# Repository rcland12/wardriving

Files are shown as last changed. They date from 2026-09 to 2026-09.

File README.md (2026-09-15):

# rustypi wardriver

A self-contained, touch-driven wardriving rig built on a Raspberry Pi 4B. Power it on and
it boots straight into a full-screen touch UI on a 3.5" LCD. Tap **START** to capture Wi-Fi
and Bluetooth, watch networks scroll by with live GPS and capture stats, and tap **STOP** to
close out the session. Upload finished sessions to WiGLE or your home server from the menu.

<p>
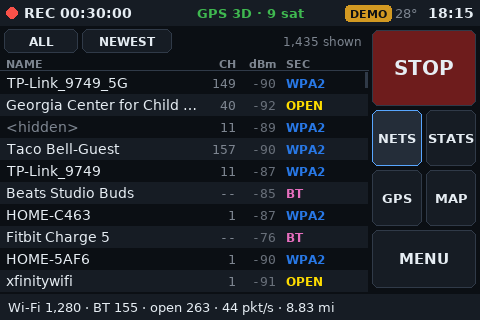
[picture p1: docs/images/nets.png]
Network list

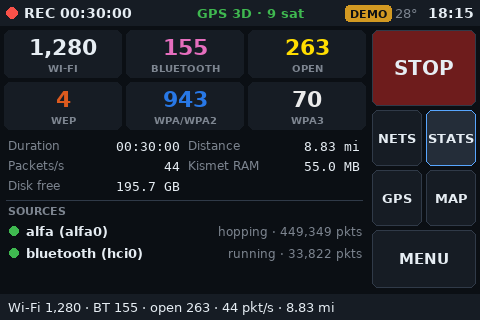
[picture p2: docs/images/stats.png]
Stats view

</p>

> **Status:** alpha. Capture, GPS, Bluetooth, touch calibration and boot-to-UI work on the Pi;
> WiGLE and home-server uploads are implemented. Not yet road-tested.

---

## Hardware

| Part | Model | Role | Linux view |
|---|---|---|---|
| SBC | Raspberry Pi 4 Model B (2 GB) | Host | Raspberry Pi OS Lite 64-bit (Debian 13 "Trixie") |
| Wi-Fi | ALFA AWUS036ACM (MediaTek MT7612U, dual-band) | Capture radio, monitor mode | `alfa0`, pinned by driver match; in-kernel `mt76x2u` |
| Bluetooth | Pi 4 onboard radio | BT classic + BLE capture | `hci0` |
| GPS | GlobalSat BU-353N (USB) | Location + time source | `/dev/serial/by-id/usb-Prolific_…` (NMEA, 4800 baud) |
| Display | OSOYOO 3.5" HDMI LCD, 480x320, resistive touch | UI | HDMI `HDMI-A-1` + ADS7846 touch on SPI0 CE1, IRQ GPIO25 |

The onboard Wi-Fi (`wlan0`) stays in managed mode for SSH and uploads. Only the ALFA captures.

**Display wiring:** video goes over HDMI. Touch uses GPIO header pins 19–26 (SPI MOSI, MISO,
SCLK, CE0, CE1, GPIO25 IRQ, GND). The screen is powered separately, so the 5V pins aren't
needed.

**Orientation:** landscape, rotated 180° so the HDMI adapter points down.

**Case and mount:** a 3D-printable enclosure and dash mount for this exact Pi + screen stack
is in [`case/`](case). See [Case and mount](#case-and-mount).

---

## How it works

```
               ┌──────────────────────────── Raspberry Pi 4B ─────────────────────────────┐
 BU-353N ──USB─┼─► gpsd ──┬──────────────► chrony (sets system clock from GPS; no RTC)    │
               │          ├──────────────► Kismet ◄── alfa0 (monitor mode, 2.4 + 5 GHz)   │
               │          │                  │    ◄── hci0  (Bluetooth / BLE)             │
               │          │                  │  └─► /var/lib/wardrive/logs/*.kismet       │
               │          │                  │                          *.wiglecsv        │
               │          ▼                  ▼ REST API (127.0.0.1:2501)                  │
               │     ┌──────────── wardrive-ui (Python + pygame → /dev/fb0) ─┐            │
               │     │ status bar · nets · stats · gps · map · menu · upload │──► HDMI ───┼─► 3.5" LCD
               │     │ start/stop via systemd · shutdown · WiGLE/home upload │◄── SPI ────┼── touch
               │     └───────────────────────────────────────────────────────┘            │
               └──────────────────────────────────────────────────────────────────────────┘
```

- **Kismet** (from the official Kismet apt repo) does the capture work: monitor mode, channel
  hopping, BLE scanning, GPS tagging, and writing `.kismet` and WiGLE CSV logs. It runs as
  `wardrive-kismet.service`. That service isn't enabled at boot; the START button starts it.
- **gpsd** owns the GPS and polls even with no clients (`-n`), so a fix is ready before you tap
  START. **chrony** takes time from it, so log timestamps are right even with no network.
- **wardrive-ui** draws each frame off-screen with pygame, then copies it into `/dev/fb0`, the
  kernel framebuffer the text console uses. There's no X11, Wayland, or desktop. It renders a
  480x320 canvas, flips it 180°, and scales it to the HDMI mode. It reads the touch panel
  through evdev and maps coordinates with its own 4-point calibration, which covers the axis
  swap and rotation. It controls Kismet through a narrow sudoers rule.
- **systemd** starts the UI on `tty1` in place of the login prompt, about 14 s after power-on,
  and restarts it if it crashes. If the UI restarts mid-capture, it picks the running session
  back up.

### Display notes (OSOYOO 3.5" HDMI)

The OSOYOO panel reached a working setup in three steps:

| Attempt | Result | Why |
|---|---|---|
| Force native `480x320` | "No Signal" | 60 Hz at that size needs an 11.9 MHz pixel clock; HDMI's minimum is 25 MHz |
| Force `640x480` | Signal, but black | The panel lists it in its EDID but doesn't display it |
| **No forced mode** | ✅ Works | The Pi uses the panel's preferred **1280x720**, and the panel's scaler shrinks it to 480x320 |
| SDL straight to DRM/KMS | Black | The UI's buffer reached the display but never showed (likely its alpha channel) |
| **Copy frames into `/dev/fb0`** | ✅ Works | The same opaque buffer the text console uses |

Rotation uses `fbcon=rotate:2`, which flips only the console text. `video=…,rotate=180` would
also rotate everything drawn on the screen, and the app already flips its own frames.
`scripts/display-test.sh` checks each display path one at a time if you change screens.

---

## The UI

| | |
|---|---|
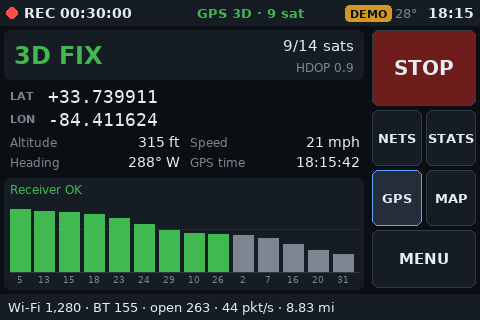
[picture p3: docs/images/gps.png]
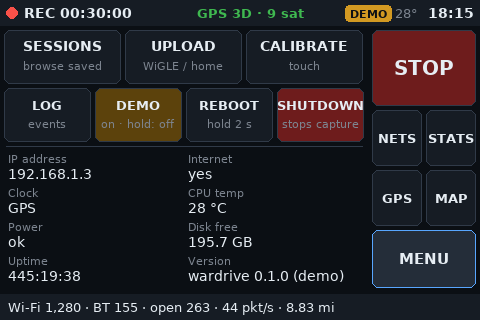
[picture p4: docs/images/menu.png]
|  |  |
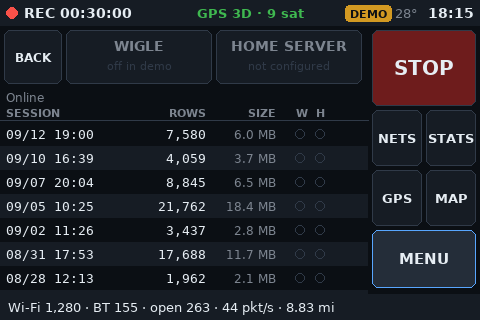
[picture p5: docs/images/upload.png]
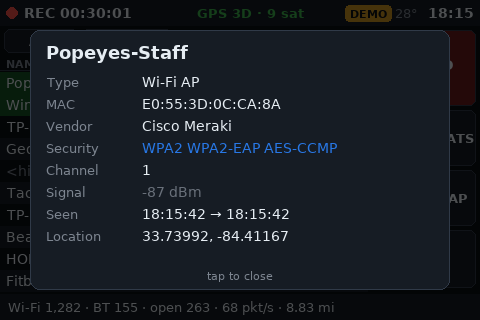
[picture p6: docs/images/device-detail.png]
|  |  |
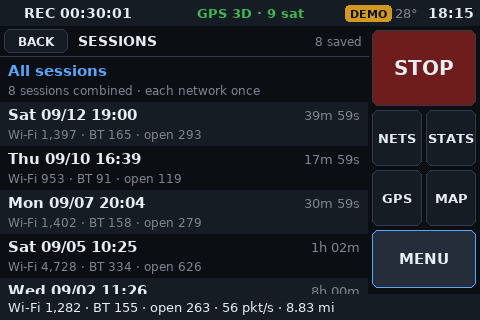
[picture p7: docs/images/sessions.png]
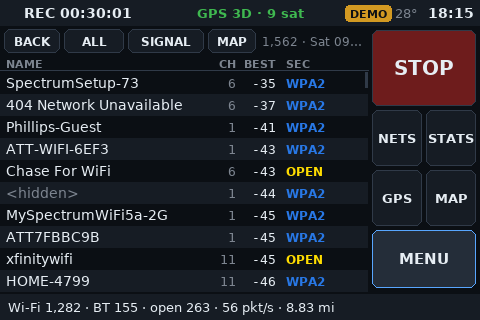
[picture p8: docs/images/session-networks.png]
|  |  |
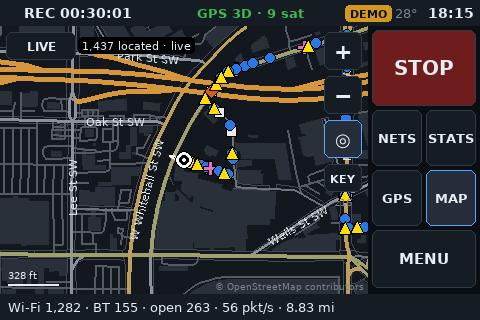
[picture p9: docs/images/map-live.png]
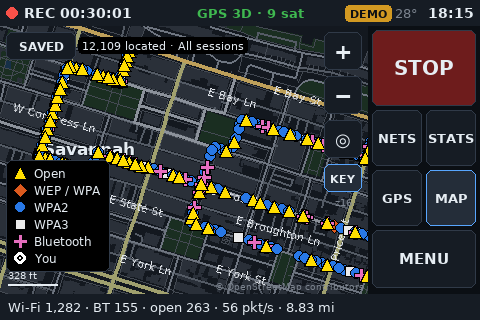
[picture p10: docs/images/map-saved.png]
|  |  |

*(Screenshots use [demo mode](#demo-mode).)*

| View | Shows |
|---|---|
| **NETS** | Live list of Wi-Fi APs and Bluetooth devices. Filter ALL/WIFI/BT; sort newest or strongest. New devices flash green. Tap a row for details. Drag to scroll. |
| **STATS** | Wi-Fi, BT, and per-security counts, duration, distance, packets/s, Kismet RAM, free disk, capture source health. |
| **GPS** | Fix type, satellites, HDOP, lat/lon, altitude, speed, heading, GPS time, clock source. |
| **MAP** | Offline street map (see [Install an offline map](#5-install-an-offline-map-optional)). **LIVE** follows your GPS position and plots networks as they're located; **SAVED** plots a finished session or all of them. Each dot's shape and color show its security: ▲ yellow open, ◆ orange WEP/WPA, ● blue WPA2, ■ white WPA3, ✚ pink Bluetooth; **KEY** shows the legend. The colors are chosen to stay distinct with color blindness, and the shapes work without color at all. Drag to pan, **+**/**−** to zoom, **◎** to re-center and follow. Tap a dot for details. |
| **MENU** | SESSIONS, UPLOAD, CALIBRATE touch, LOG, [DEMO](#demo-mode) (hold 2 s), REBOOT and SHUTDOWN (hold 2 s), IP address, internet, power, temp, disk. |
| **LOG** | App and Kismet events (source errors, GPS fix gained or lost, start/stop). Tap for full text. |
| **SESSIONS** | Finished capture sessions (date, duration, Wi-Fi/BT/open counts, whether archived), plus "All sessions" with each network listed once. Tap one to browse every network it recorded: WIFI/BT filter, sort by strongest signal, name or newest, and tap for details (security and WPS, frequency, strongest signal, packets, sessions seen in, location). **MAP** shows them on the map. |
| **UPLOAD** | Finished sessions with GPS row counts and upload state; one button each for WiGLE and your home server. |

The status bar shows recording time, GPS fix and satellites, CPU temp, a `PWR!` warning for
under-voltage or throttling, and the clock. The footer shows live totals, the last session,
or errors.

---

## Case and mount

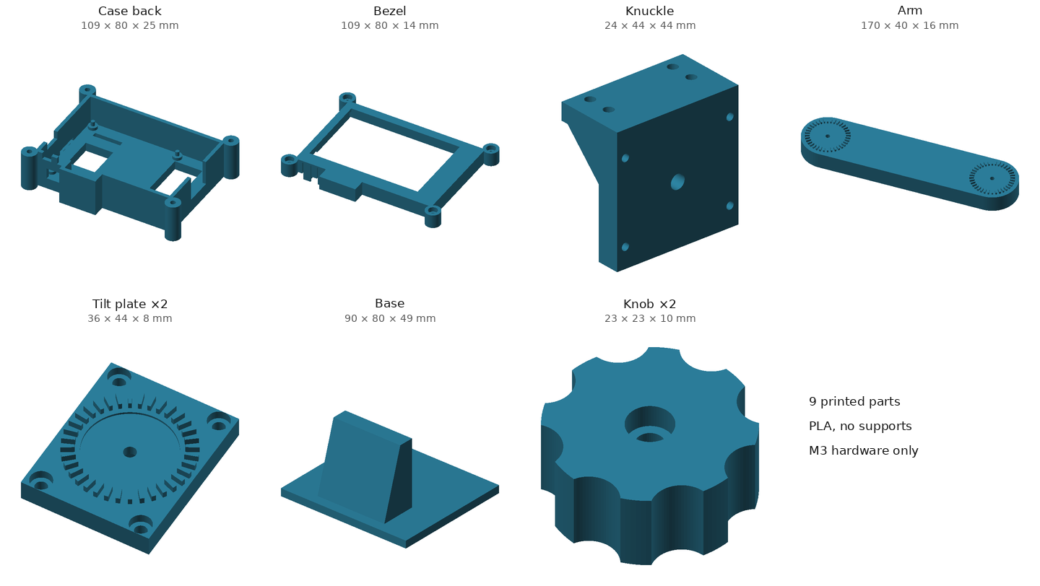
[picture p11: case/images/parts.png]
The nine printed parts of the case and dash mount


A 3D-printable enclosure and car-console mount designed around this exact Pi 4B + OSOYOO
screen stack:
- **Parts:** 9 printed parts, PLA, no supports, M3 hardware only
- **Mount:** an arm with two 10°-step toothed tilt joints, attached to the console with VHB
- **Screen retention:** the bezel clamps the screen by its glass border through foam, so the
  display can't work loose from the GPIO header under vibration
- **Buttons:** flex tabs in the bezel reach the screen's power and backlight buttons

**Full build guide: [`case/README.md`](case/README.md)**, covering parts, hardware, assembly
and design notes. Print settings are in [`case/docs/PRINTING.md`](case/docs/PRINTING.md).

| Files | For |
|---|---|
| [`case/models/stl/`](case/models/stl) | Printing, in any slicer |
| [`case/models/step/`](case/models/step) | Editing in any CAD tool |
| [`case/models/f3d/`](case/models/f3d) | Editing in Fusion 360 |
| [`case/scripts/fusion_build.py`](case/scripts/fusion_build.py) | The parametric source that generates every part |

Print order in brief: both tilt plates first (check that the teeth mesh), then the bezel
(dry-fit it on the screen), then everything else.

---

## Setup

### 1. Flash the Pi
Raspberry Pi OS **Lite** (64-bit). No desktop is needed. In Raspberry Pi Imager, set the
hostname, user, Wi-Fi, SSH key, and Wi-Fi country.

### 2. Deploy from a dev machine
```bash
git clone git@github.com:rcland12/wardriving.git && cd wardriving
./scripts/deploy.sh rustypi7 --boot --reboot
```
Or run it on the Pi from a clone:
```bash
sudo ./scripts/install.sh && sudo ./scripts/boot-config.sh && sudo reboot
```

`install.sh` is idempotent. It does the following:

1. Installs gpsd, chrony, pygame, evdev, `libdrm-tests` (for `display-test.sh`), and Kismet
   (`kismet-core` plus the linux-wifi and linux-bluetooth capture helpers) from Kismet's repo.
2. Pins the ALFA as `alfa0` and tells NetworkManager to leave it alone.
3. Configures gpsd for the GPS and adds it to chrony as a time source.
4. Writes `/etc/kismet/kismet_site.conf`, creates `/var/lib/wardrive/logs`, generates Kismet
   REST credentials in `~/.kismet/kismet_httpd.conf`, and unblocks Bluetooth.
5. Installs `wardrive-kismet.service`, the sudoers rule, `/opt/wardrive`, and
   `/etc/wardrive/wardrive.toml` (created from the example only if it doesn't exist yet).
   Then it enables `wardrive-ui.service`.

`boot-config.sh` edits `/boot/firmware` and keeps timestamped backups. It's idempotent, and
`--remove` undoes it:

- **`config.txt`:** `dtparam=spi=on`, the `ads7846` touch overlay (`cs=1`, `penirq=25`), and
  `disable_splash=1`
- **`cmdline.txt`:** `fbcon=rotate:2` (console upside-down to match the mount), hidden cursor,
  no console blanking, quiet boot. No `video=` mode is forced (see
  [Display notes](#display-notes-osoyoo-35-hdmi)). Options:
  `WARDRIVE_QUIET=0` shows boot messages, and `WARDRIVE_HDMI_MODE` forces a mode.

### 3. First boot: calibrate touch
With no calibration saved, the UI opens the calibration screen. Tap the four corner
crosshairs, then the center one to verify. Use the stylus. Then tap around the test pad and
hit DONE. The calibration is saved to `~/.config/wardrive/touch.json`. To redo it later, go
to **MENU → CALIBRATE**.

### 4. Configure uploads (optional)
Edit `/etc/wardrive/wardrive.toml` on the Pi. It's readable only by root and your user, and
is never committed. See [`config/wardrive.toml.example`](config/wardrive.toml.example).
```toml
[upload.wigle]
enabled = true
api_name = "AID..."        # from https://wigle.net/account
api_token = "..."

[upload.home]
enabled = true
url = "https://api.example.com/wardrive/upload"

[upload.home.headers]      # Cloudflare Access service token for this Pi only
CF-Access-Client-Id = "<id>.access"
CF-Access-Client-Secret = "<secret>"
```
Then check the credentials without uploading anything, and restart the UI:
```bash
cd /opt/wardrive && python3 -m wardrive --test-upload
sudo systemctl restart wardrive-ui
```

The home upload gzips each `.kismet` and `.wiglecsv` file and POSTs it to the
`/wardrive/upload` endpoint of your home API, which stores it under
`api/data/wardrive/<session>/`. Files must be under 95 MB after compression, because of
Cloudflare's body limit. Re-sending an identical file is harmless.

### 5. Install an offline map (optional)
The MAP screen works without internet. It reads a prebuilt map file from
`/var/lib/wardrive/maps/`, which you build on a dev machine from an
[OpenStreetMap](https://www.openstreetmap.org) extract. One US state is a few hundred MB.

```bash
source ~/.global_venv/bin/activate && pip install osmium shapely numpy
curl -fLO https://download.geofabrik.de/north-america/us/georgia-latest.osm.pbf
tools/build_map.py georgia-latest.osm.pbf -o georgia.map --name Georgia   # ~25 min, ~1.2 GB RAM
./scripts/push-map.sh georgia.map rustypi7                                # copy to the Pi, restart the UI
```

What's in the map, and the zoom level where it appears:

| Zoom | Features |
|---|---|
| 6+ | Interstates, city names |
| 9–13 | Highways and main roads, towns, large lakes and parks, rivers |
| 14–15 | All streets, villages and neighborhoods, small parks and ponds, streams |
| 16+ | Buildings, street names, service roads and driveways |
| 17–18+ | Shops and amenities, then house numbers |

The file is SQLite with compressed vector tiles at four levels of detail, drawn directly with
pygame. There's no tile server and no network access. On a Pi 4, street-level views render in
about 5–40 ms, and the whole-state view in about a quarter second (a second the first time).
Panning moves the already-drawn image, so it stays smooth. Only one map is used at a time: the
first `*.map` in the directory, alphabetically. Georgia comes to about 250 MB.

Buildings, businesses and house numbers appear only where someone has mapped them in
OpenStreetMap. Downtowns are usually complete; some suburbs have roads only. Rebuild from a
fresh extract to pick up new edits.

Map data © OpenStreetMap contributors, available under the
[Open Database License](https://www.openstreetmap.org/copyright). The attribution shows on the
map screen.

---

## Demo mode

Try everything indoors, with no GPS signal and no real networks: **MENU → hold DEMO**.
The UI restarts with a **DEMO** badge in the status bar, and:

- **GPS** gets a simulated fix at your demo start point.
- **START** drives a simulated car along the offline map's real roads. The network list,
  stats and live map fill up as it hears the routers in nearby houses and businesses. With
  no map installed, it drives a plain street grid instead.
- **STOP** saves the drive as `.kismet` and `.wiglecsv` files, so SESSIONS, MAP and UPLOAD
  all work on it.
- **SESSIONS** starts with 8 simulated past drives from the last three weeks: short errands,
  longer loops around town, and one trip to another city. The same streets have the same
  routers on every drive, so "All sessions" shows networks seen more than once. One drive
  starts with the clock wrong, like a real boot away from Wi-Fi.
- **UPLOAD → HOME SERVER** sends demo sessions to a separate `_demo` folder on the server.
  If the server doesn't support that yet, the Pi refuses and sends nothing.
- **WiGLE uploads are off** in demo mode. Every demo file is marked as simulated, and
  `tools/wardrive_review.py` won't send marked files to WiGLE.

**MENU → hold DEMO** again deletes the demo data and switches back. Your real logs, upload
records and settings aren't touched in either direction. Everything demo mode writes is
under `/var/lib/wardrive/demo/`.

Set the start point to a public spot in your town in `/etc/wardrive/wardrive.toml`:
```toml
[demo]
lat = 33.7490
lon = -84.3880
```

The same controls work from SSH:
```bash
./scripts/demo.sh on           # create demo data (about 20 s on a Pi 4), restart the UI
./scripts/demo.sh status
./scripts/demo.sh regenerate   # new simulated drives
./scripts/demo.sh off          # delete demo data, back to real capture
```

On a desktop, `python -m wardrive --mock --window` runs demo mode with its own data in
`~/.local/state/wardrive/mock-demo`.

On the server, review demo uploads with `tools/wardrive_review.py --demo list` (and `check`
or `fix`). They make good practice for the clock-step and security repairs.

---

## Using it

1. Power on the screen and the Pi together. Put the GPS where it can see the sky.
2. Tap **START**. Until the clock is set from GPS, the button shows **CANCEL / for GPS time**
   and the status bar shows **GPS TIME…**. Capture starts as soon as the time is set, so every
   record has a correct timestamp. At home on Wi-Fi, it starts immediately.
3. Drive, then tap **STOP**. Kismet closes its logs, and a session summary pops up.
4. **MENU → hold SHUTDOWN** before cutting power. If a capture is still running, it's stopped
   cleanly first.
5. **MAP** shows where you've been. Switch it to **SAVED**, or open a session from
   **MENU → SESSIONS** and tap **MAP**.
6. At home on Wi-Fi, go to **MENU → UPLOAD → HOME SERVER** to archive the session, then review
   and publish it from the server (below).

Get logs directly (never deletes anything):
```bash
./scripts/pull-logs.sh rustypi7      # -> ./logs/ (gitignored)
```

### Review, repair, then publish to WiGLE

Sessions go to your own server first, and nothing reaches WiGLE until you've reviewed it.
`tools/wardrive_review.py` (standard library only) works on the server's session directory:

```bash
tools/wardrive_review.py list                 # sessions and status
tools/wardrive_review.py check latest         # validate; exit code 1 on problems
tools/wardrive_review.py fix latest           # write review/<session>.wiglecsv (originals untouched)
tools/wardrive_review.py wigle latest --dry-run
tools/wardrive_review.py wigle latest         # upload the reviewed file; refuses on FAIL or re-upload
tools/wardrive_review.py wigle-status         # WiGLE processing status
```

`check` looks for:
- **Clock changes mid-capture.** Stale and correct FirstSeen times get grouped into clusters,
  and the offset is measured to ±1 s from the Kismet database's packet order.
- **Wrong security type.** Each row is compared with what Kismet recorded for that BSSID.
- Rows without coordinates, implausible times, GPS jumps, and duplicates.

`fix` shifts (or, with `--drop-stale`, removes) rows with the wrong time, rebuilds AuthMode
from the database, and removes duplicates.

> **Kismet 2025.09 bug:** its live WiGLE CSV writer leaves out WPA/RSN details (every network
> looks open) and marks every encrypted network as WPS. The Kismet database has the correct
> values, and `fix` rebuilds them from it. Always run `fix` before uploading.

Settings are in `~/.config/wardrive/review.env` (`chmod 600`):
```
WARDRIVE_DATA=/path/to/api/data/wardrive
WIGLE_API_NAME=AID...        # wigle.net → Account → API Name
WIGLE_API_TOKEN=...          # API Token (not "Encoded for use")
WIGLE_DONATE=on              # allow WiGLE commercial use of your uploads
```
With this setup, leave `[upload.wigle]` on the Pi unconfigured.

### Analyzer web app

`analyzer/` is the web app for every uploaded session, deployed from the rustyserver stack at
https://wardrive.russellland.dev behind Keycloak: a map of every network and Bluetooth device
(street, dark and satellite basemaps, routes, clustering, heatmap), filters that stay in the URL,
a details panel with signal over time and where each device was heard, stats, and a Sessions
page that runs the same check / fix / WiGLE upload as the tool above.

When the Pi uploads, the home API stores the files and tells the analyzer, which loads the
session into Postgres. Reviews and WiGLE upload records live there too; the uploaded files are
never modified. Details in [analyzer/README.md](analyzer/README.md).

---

## Development

The UI runs anywhere pygame does, using a simulated backend:

```bash
source ~/.global_venv/bin/activate
pip install pygame requests pytest
python -m wardrive --mock --window                # demo mode in a desktop window, mouse = touch
python -m wardrive --screenshot docs/images       # render every screen to PNG (headless, demo data)
python -m pytest -q tests                         # calibration, parsing, uploads, UI dispatch
./scripts/deploy.sh --ui-only                     # sync UI code to the Pi and restart it
```

On the Pi:
```bash
journalctl -u wardrive-ui -f                      # UI log
journalctl -u wardrive-kismet -f                  # capture log
sudo systemctl kill -s USR1 wardrive-ui           # save the live screen to /tmp/wardrive-screen-<view>.png
cgps                                              # GPS sanity check
sudo evtest /dev/input/by-path/*spi*              # raw touch events
chronyc sources                                   # is GPS feeding the clock?
```

### Repository layout
```
wardrive/            touch UI package (python3 -m wardrive)
  app.py             main loop, frame (status bar / nav / footer), modals
  backend.py         Kismet service control + REST polling -> State
  kismet.py gps.py sysinfo.py uploads.py
  touch.py           evdev reader + affine calibration
  display.py theme.py widgets.py fmt.py state.py config.py
  sessions.py        finished-session browser: reads .kismet databases, cached
  mapdata.py         offline map file format and reader
  maprender.py       map renderer (pygame + numpy) and network dots
  demo/              demo mode: simulated drives (world.py), Kismet-format files (files.py), backend
  mock.py            minimal in-memory backend for fast UI tests
  views/             nets, stats, gps, map, log, menu, sessions, upload, calibrate
config/              kismet_site.conf, wardrive.toml.example
system/              systemd units, sudoers, NetworkManager/chrony/link files
scripts/             install.sh, boot-config.sh, deploy.sh, pull-logs.sh, push-map.sh, demo.sh, display-test.sh
tools/               wardrive_review.py (server-side review, repair and WiGLE upload)
                     build_map.py (OpenStreetMap extract -> offline .map file)
analyzer/            web app (SvelteKit + Postgres): map, filters, stats, review and WiGLE upload
case/                3D-printable case and dash mount: models, build script, print guide
tests/               hardware-free tests
docs/images/         screenshots (simulated data)
```

---

## Troubleshooting

| Symptom | Check |
|---|---|
| Screen upside down | Set `display.rotate` in `wardrive.toml` (0 or 180) and `WARDRIVE_ROTATE` for `boot-config.sh`, then recalibrate |
| Touch lands in the wrong place | MENU → CALIBRATE. If you can't reach the menu: `rm ~/.config/wardrive/touch.json && sudo systemctl restart wardrive-ui` |
| No touch device | `grep -A4 ADS7846 /proc/bus/input/devices`. Try `WARDRIVE_TOUCH_CS=0 sudo ./scripts/boot-config.sh` |
| "No Signal" | Remove any forced mode: `sudo ./scripts/boot-config.sh` (don't set `WARDRIVE_HDMI_MODE`). Check the pixel clock: `sudo grep 'mode: "[0-9]' /sys/kernel/debug/dri/*/state` (second number, kHz, must be ≥ 25000) |
| Signal but black UI | Console visible when the UI is stopped? Run `sudo PHASES="C D E" ./scripts/display-test.sh` and watch which phases appear. Keep `display.backend = "fbdev"` |
| Screen dead after boot changes | `sudo ./scripts/boot-config.sh --remove && sudo reboot` restores the original boot files |
| GPS NO FIX forever | Get a sky view (it won't lock indoors). Check `cgps` |
| Bluetooth source error | `sudo rfkill unblock bluetooth` |
| START → ERROR | MENU → LOG, then `journalctl -u wardrive-kismet -b` |
| DEMO badge, networks look made up | Demo mode is on: MENU → hold DEMO (or `./scripts/demo.sh off`) |
| MAP says "No map installed" | `ls /var/lib/wardrive/maps/` should list a `.map` file; see [Install an offline map](#5-install-an-offline-map-optional). `journalctl -u wardrive-ui` shows why a file was skipped |

---

## Legal and privacy

- Passive collection of broadcast beacons is generally legal in the US. Don't connect to,
  deauth, or attack networks you don't own. Check your local laws.
- Capture logs contain precise location history and nearby device identifiers. `logs/` and
  capture file types are gitignored. **This repo is public: keep it that way.**
- Kismet REST credentials and upload tokens live only on the Pi.

---

## License

[MIT](LICENSE) © 2026 Russell Land

This project installs and talks to other software but doesn't include its code. Those
projects keep their own licenses: [Kismet](https://www.kismetwireless.net/) (GPL-2.0, run as
a separate service over its REST API), gpsd (BSD-2-Clause), chrony (GPL-2.0), and pygame
(LGPL-2.1).

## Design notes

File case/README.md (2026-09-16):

# Case and dash mount

A 3D-printable enclosure and articulated car-console mount for the wardriver: a
Raspberry Pi 4B with the OSOYOO 3.5" HDMI touch screen on top. It's designed around
those exact boards, including the screen's glass border, its rigid HDMI adapter and
its two side buttons, so it fits this stack specifically.

Printed parts

- **9 printed parts** (7 designs; the tilt plate and knob are printed twice), PLA,
  **no supports**
- **M3 hardware only**, no screws into the Pi
- Two **10°-step toothed tilt joints**: one leans the arm to cancel the console's
  slope, the other tilts the screen
- Flex buttons in the bezel reach the screen's PWR and backlight buttons
- Every part is generated by `scripts/fusion_build.py`, so a changed measurement
  rebuilds the whole model

Back to the [main project](../README.md).

---

## The build

Screen facing you, landscape, GPIO edge up, cables out the bottom (the HDMI adapter
points down, matching the software's 180° rotation):

```
                    GPIO header edge (up)
      +-------------------------------------------------------+
      |  +-------------------------------------------------+  |
 LCD  |  |                                                 |  |  USB-A: GPS +
power |  |          3.5" screen (lit area)                 |  |  Wi-Fi adapter,
 cord |  |                                                 |  |  both in the
 <==  |  +-------------------------------------------------+  |  black USB2 stack
SD    |                                                       |  ==>
slit  +--[PWR]-[BKL]------+=================+-----------------+
         flex buttons     |  adapter hood   |
         (bottom face)    +=================+
       Pi power cord exits down
                              |
                      [ tilt joint ]   10° steps, tilts the screen up/down
                              |
                          206mm arm
                              |
                      [ tilt joint ]   leans the arm, cancels console slope
                      [ base plate ]   3M VHB to the console
```

Reference photos of the Pi + screen stack the case was measured from are in
[`images/`](images).

---

## Parts

| Body | Qty | Size (mm) | Print orientation | Notes |
|---|---|---|---|---|
| `01_case_back` | 1 | 108.6 × 79.6 × 25.4 | back face down | Pi pocket, port openings, open back, 23 vent slots, 4 corner ears, adapter hood |
| `02_case_bezel` | 1 | 111.3 × 79.6 × 22.0 | **flip: front face down** | 9.5 thick; flex-button tabs hang 4.1 below it; stylus tube at top-left reaches 22 back from the face |
| `03_tilt_plate` | **2** | 36 × 44 × 7.8 | teeth up | One on the case, one on the base |
| `04_arm` | 1 | 246.2 × 40 × 15.8 | **lying flat, rotated 45° on the bed** | Toothed hub at both ends. Too long to lie straight on a 225 mm bed |
| `05_base` | 1 | 90 × 80 × 49 | plate down | Buttressed wall with a vertical mounting face |
| `06_knob` | **2** | 23.3 × 23.3 × 10 | head pocket up | Tilt bolt's head presses into it |
| `07_knuckle` | 1 | 24 × 44 × 44 | **flip: foot down** | Turns the top joint so it tilts the screen |

The shell itself is 93.6 × 64.1 mm; the sizes above include the corner ears and the
adapter hood (a 25.7 × 8 mm bump on the bottom edge). The assembled case is 34.9 mm
thick. Expect roughly 190–220 g of PLA at the settings in the print guide.

| Files | Use |
|---|---|
| [`models/stl/`](models/stl) | One STL per part, for any slicer |
| [`models/3mf/`](models/3mf) | The same parts as 3MF (geometry only) |
| [`models/step/`](models/step) | The whole design as STEP, editable in any CAD tool |
| [`models/f3d/`](models/f3d) | Fusion 360 archive of the parametric model |

---

## Printing

**Full guide: [`docs/PRINTING.md`](docs/PRINTING.md)**: settings, per-part
overrides, print order and post-processing. The short version:

- PLA, 0.4 mm nozzle, 0.2 mm layers, **4 walls**, 5 top/bottom layers, 25 % gyroid,
  **supports off**
- Only two parts need turning over on the bed: the **bezel** goes front face down,
  the **knuckle** goes foot down
- Set **line width 0.40 mm on the bezel** so its 1.2 mm flex buttons print as exactly
  three lines
- **Print the bezel first** and dry-fit it on the screen. It has the tightest
  tolerances, so any problem turns up after 12 g of plastic instead of 200 g

Built and tested on an Elegoo Neptune 3 Pro with Cura. Sliced G-code isn't included,
because it only works on the printer and profile it was sliced for.

---

## Hardware (M3 only)

| Qty | Item | Where | Why this length |
|---|---|---|---|
| 4 | **M3 × 30 socket head** + nut | Bezel to back shell | Heads sit in Ø5.9 × 3.2 mm recesses in the bezel. Nut pockets are sunk 5.1 mm, so a 30 mm screw passes fully through the nut and stops 1 mm past it |
| 8 | **M3 × 8** | Knuckle foot to case back (4), top tilt plate to knuckle (4) | 4.5 mm of thread each; a longer screw bottoms out in the case floor |
| 4 | **M3 × 12** | Base tilt plate to base wall | Tapped 10 mm deep, giving 8.5 mm of thread |
| 2 | **M3 × 30 socket head** + nut + flat washer | Tilt bolts | Head sunk into the knob, nut trapped in a pocket in the knuckle / base wall behind the tilt plate, washer between knob and arm. The tip clears the nut by 1 mm |
| ~30 cm | Single-sided closed-cell foam tape, ~1 mm thick, cut into ~1.5 mm strips | Bezel lip, around the window | Fills the 0.5 mm gap so the screen can't rattle, without clamping the glass |
| — | 3M VHB tape (4991 for textured plastic) | Base to console | |

**No lock washers anywhere.** On screws threaded into plastic they bite in and the
plastic creeps, so they don't lock and can crack the part. The flat washers under the
knobs only stop tightening from grinding the arm.

---

## Assembly

1. Form the threads: run an M3 screw slowly into each tapped hole and back out (four
   in the case floor, four in the knuckle's upright, four in the base wall).
2. Press four M3 nuts into the hex pockets on the back face of the case back's corner
   ears, then lay the case back on its back. The table keeps the nuts in place while you
   work, and the hex shape stops them turning, so you never need a wrench on them.
3. **Remove the microSD card.** Plug the screen onto the Pi and lower the pair into
   the case back: the four pegs go into the Pi's mounting holes and the HDMI adapter
   drops into the hood.
4. Stick foam strips around the underside of the bezel's window lip, adhesive side on the
   bezel. Keep them on the lip and out of the window: the glass border is only 1.6 mm on
   the top edge.
5. Lower the bezel on. The two flex tabs slide into the notches in the bottom wall and
   the cap closes over the hood.
6. Drive four M3 × 30 through the bezel into the nuts (2.5 mm hex key), a few turns each
   in a criss-cross order. Stop when the bezel meets the case back all the way round and
   the screws are snug. Don't crank them: PLA ears crack and nuts get pulled out of their
   pockets. If a nut spins or pushes out, hold it with a fingertip from below, or fix it
   with a drop of CA glue. If the seam won't close without force, the foam is too thick.
7. **Test the buttons:** press each tab on the bottom face; you should feel the
   screen's button click.
8. Push the microSD card back in through the slit on the left side.
9. Drop an M3 × 30 head-first into each knob's round pocket. It slides freely for the
   first 3 mm, then meets a tight seat. Pull it home with a nut and washer on the thread
   under the knob, then take them off. You can also warm the head for a few seconds with
   a soldering iron and push it in.
10. Lay the knuckle and the base with their mounting faces up, and press a nut into the
    hex pocket in the middle of each face. If one won't stay put, use a drop of CA glue.
    Bolt one tilt plate over the knuckle's upright with its long side along the case
    height (4× M3 × 8), and the other over the base wall with its long side along the
    base (4× M3 × 12). The nuts end up trapped behind the plates.
11. Bolt `07_knuckle` to the case back through its foot (4× M3 × 8, driven down the
    tunnels in the gusset). The plate on the upright doesn't block the tunnels.
12. At each joint: flat washer on the knob's bolt, then through the arm into the
    plate's nut. **Rotate the plate half a tooth (5°) against the arm so the teeth
    interleave.** Square-on they sit tip-to-tip and won't seat. Set the angle, then
    tighten.
13. Clean the console with isopropyl alcohol and stick the base down with VHB. The arm
    leans along the base's **long side** (90 mm), so point that side where you want
    the screen to face.

---

## How it's designed

### The screen is held by its glass border, through foam

In a car, the main risk is the GPIO header slowly walking off its pins under
vibration. So the whole screen + header + Pi sandwich is clamped between the bezel and
the back shell, bolted with 4× M3 that pass **outside** both boards.

The glass covers nearly the whole screen board (84.13 × 54.82 mm on an 85 × 56 board),
so there's no bare PCB for the bezel to press on. The bezel lip lands on the **glass
border** instead, outside the lit area, with at least 1.6 mm of border on every side
(2.0 left, 7.7 right, 3.3 bottom, 1.6 top). The pocket leaves 0.5 mm for a strip of
thin foam, so the screen is held firmly without the lip pressing hard on the glass.
Heavy pressure on a resistive touch panel can cause phantom touches.

**The Pi has no screws.** Its mounting holes are 2.75 mm and an M3 won't pass, so it
sits on four locating pegs and the bezel clamps it through the screen.

### The HDMI adapter gets its own hood

The rigid adapter reaches 10.34 mm past the Pi's edge, well beyond a normal wall.
Instead of making the whole case taller, a local hood on the bottom edge encloses just
the adapter with 0.6 mm clearance, and the bezel carries a matching cap. The rest of
the case keeps its normal size, with a near-even border around the screen.

### PWR and BKL are flex buttons built into the bezel

The screen's two buttons sit on its bottom edge, about 2.4 mm inside the case wall.
Each gets a 5 mm-wide tab cut into the bezel's bottom wall: flush with the outside,
hinged at the bezel face, hanging just past the seam into a notch in the case back. A
small wedge on its inside sits 0.3 mm from the button. Press the tab and it flexes,
and the wedge pushes the button.

The tabs are in the bezel rather than the case back because the Pi's power-cord
opening sits directly below BKL in the case-back wall, leaving no room for a tab long
enough to flex safely in PLA. BKL is only 3.4 mm from the HDMI adapter, so its tab is
shifted 0.74 mm away from the hood while its wedge stays on the button. The build
script refuses to run if a wedge can't cover a button's centre by at least ±0.75 mm.

### Ventilation

The Pi's processor faces the screen, so it sits in the 16 mm gap between the Pi and the
LCD — the hot pocket. The open back only vents the underside of the Pi's circuit board,
which blocks that air from the processor, so the vents go through the **walls, at the
height of that gap**: 23 vertical slots, 3 mm wide, about 1030 mm² of opening.

| Wall | Slots | Notes |
|---|---|---|
| Top (GPIO edge) | 13 | Mounted, this edge faces up: the exhaust |
| Bottom (power edge) | 6 | Right of the adapter hood: the intake. The rest of that wall is the power jack, button notches and hood |
| Left | 4 | Between the LCD power notch and the stylus tube, above the SD slit |
| Right | 0 | The blue USB3 stack and ethernet jack sit against it inside; the USB2 notch is already open |

With the GPIO edge up and the power edge down, hot air rises through the gap and out the
top — a chimney.

**Structure is protected by rules the build enforces:** at least 3 mm of solid rib
between slots and around every existing opening, a 2 mm solid band along the floor and the
rim (the bezel clamps down on the rim), 8 mm of solid wall at each corner (the ears carry
the bezel screws), and **no slots in the floor**, which carries the whole mount's weight
through the knuckle. Slots are vertical so each one only bridges its 3 mm width when the
case back prints.

### Stylus holder

A round tube just outside the bezel's top-left edge, below the corner ear, with its axis
perpendicular to the screen and its front flush with the screen face. Drop the stylus in
tip-first and it hangs on its paddle, which can't pass the 5.2 mm bore. The tube reaches
22 mm back from the face — past the bezel and alongside the case back with a 0.8 mm gap —
so the stylus stays straight.

The bore prints at about 5.0 mm, a snug slip fit on the 4.88 mm barrel. If the stylus
still walks out on bumps, drop `stylus_bore` to 5.1; if it won't go in, raise it to 5.3.
Either way it's a bezel reprint only. The
stylus sticks out behind the case but runs well clear of the arm at every tilt angle,
checked by `mountcheck` assuming a 110 mm stylus.

### Ports

| Opening | Where | Sized for |
|---|---|---|
| Pi power (USB-C) | bottom face | a USB-C plug overmold of 10.92 × 6.17 mm |
| Screen power (USB-C) | left side, high | the same plug size |
| USB-A | right side | the **black USB2 stack** with 16.5 mm plugs (GPS and Wi-Fi adapter). `usb3_open = 1` opens the blue USB3 stack too |
| microSD | left side slit | card inserted after the Pi is in |
| Ethernet, AV, micro-HDMI | closed | not used |

**Why the black ports.** The GPS and the Wi-Fi adapter go in the USB 2.0 stack. A USB 3.0
port running SuperSpeed radiates broadband noise around 2.4 GHz, right where the adapter
is listening, and it can raise the noise floor a GPS receiver sees as well. A USB 2.0 port
never runs SuperSpeed, and neither device needs more than 480 Mbps for scanning. The
opening is the same size as before, just moved 18 mm toward the power edge; it keeps
3 mm of wall to the corner ear.

### Why the arm prints flat

A cantilevered arm in a car is a vibration lever loaded fore and aft. Printed upright,
every layer boundary at its base is in tension, and that's where it snaps. Printed
flat, the layer lines run along the load path. That's also why it's a 40 × 14 mm fin
rather than a round post: the 40 mm side faces the bending load, and the flat profile
lets it lie on the bed with both toothed hubs facing up.

### Two tilt joints

Both ends of the arm carry the same joint: 36 teeth on a Ø34 hub, **10° steps**. The
teeth sit in a band from 13.5 to 17 mm radius, far enough out that every tooth and gap
is at least two extrusions wide.

Both bolts are horizontal and **parallel to the screen's long edge**, like a desk lamp:

- The **base joint leans the arm** toward or away from the direction the screen faces.
  That also cancels the console's slope, so no wedge is needed.
- The **top joint tilts the screen** up and down. The screen always stays level in
  landscape.
- **The screen faces the direction the arm leans.** Lean the arm L degrees and set the
  top joint to the same L, and the screen stands upright facing along the lean. That's
  checked collision-free for every lean from 0° to 90°.

The top joint connects through `07_knuckle`, an L-bracket that holds the joint 23 mm
behind the case, so the arm's rounded end clears the case at every angle. From upright,
the screen can tilt 180° before the arm would hit the case back.

The bolt only provides clamping force; the teeth carry the load. So M3 is plenty, and a
positive tooth lock can't creep the way a friction joint does. Braking at 1 g with
a ~250 g payload at ~234 mm is about 0.6 N·m, or ~38 N spread over 36 teeth. **Snug the
knob, don't crank it.** The straight-sided teeth hold the angle on their own.

**The nut sits behind the tilt plate, not in it.** Tightening pulls the nut toward the
arm at the plate's centre while the arm pushes back on the tooth ring 13.5 mm out, so
the middle of the plate is loaded in bending. The first design had the nut pocket in the
plate, which left a 2.7 mm web over a bridged pocket roof, and even light hand-tightening
caved the centre in. Now the nut sits in a pocket in the knuckle's upright or the base
wall and bears on the plate's solid 5.4 mm centre, which is about 4× as strong. The
knob's bolt head is sunk 3 mm deeper so an M3 × 30 still reaches through the nut.
`fitcheck` checks that the tip clears the nut and stays inside the bolt-tip hole.

| | mm above console floor |
|---|---|
| Base pivot | 28 |
| Top pivot, arm vertical | 234 |
| Case bottom face, arm vertical, screen upright (where the power cords exit) | ~202 |

Leaning the arm lowers everything: the top pivot sits at 28 + 206 × cos(lean) mm.

---

## Customizing

All geometry and parameters live in one file, [`scripts/fusion_build.py`](scripts/fusion_build.py).
The most useful parameters in its `PARAMS` table:

| Parameter | Default | Effect | Reprint |
|---|---|---|---|
| `arm_h` | 206.2 mm | Arm length, pivot to pivot. Every 10 mm added raises the cord exit by 10 mm | arm only |
| `stylus_bore` | 5.2 mm | Stylus tube bore. Smaller = firmer grip on the 4.88 mm barrel | bezel only |
| `vent_w` / `vent_rib` | 3 mm / 3 mm | Vent slot width and the solid rib between slots. Slot count adjusts automatically | case back only |
| `nub_gap` | 0.3 mm | Flex-button wedge to button. Lower it if a button doesn't click, raise it if one is held down | bezel only |
| `adp_hood` | 1 | 0 = open notch instead of a hood (the adapter then pokes ~5 mm out of the case) | case back, bezel |
| `usb2_open` / `usb3_open` | 1 / 0 | Which USB-A stack the case opens: black USB2 by default, blue USB3 with `usb3_open`. Both = one merged notch | case back |
| `kn_gusset_ang` | 30° | Slope of the knuckle's brace. Lower = the foot screws nearest the upright sit less deep in their tunnels (4.8 mm at 30°, 9 mm at 45°) | knuckle only |

Without Fusion 360, import the STEP file into any CAD tool to modify a part.

### Rebuilding the model

`fusion_build.py` is written as numbered stages of Fusion 360 API Python. `scripts/push.py`
sends them to a Fusion add-in that runs scripts received over HTTP (set
`FUSION_BRIDGE_URL`; the add-in isn't part of this repo), then runs the built-in checks:

```bash
python scripts/fusion_build.py --list          # stages
python scripts/push.py status
python scripts/push.py reset params 01 02 03 04 05 06 07 verify fitcheck mountcheck save
```

- `verify` fails on missing or extra bodies, overlaps, or invalid geometry
- `fitcheck` puts the case back and bezel in their **assembled** positions and checks
  them against stand-ins for the real hardware (Pi, ports, cable plugs, screen, glass,
  adapter, SD card, buttons). It then presses each flex button to confirm the wedge
  lands on the button, and checks every screw length against its nut or tapped hole
- `mountcheck` swings both tilt joints through their range in 10° steps and checks the
  arm against the base, knuckle, case and bezel at every step
- Every push is logged to `logs/build_log.jsonl` (git-ignored) with the sha256 of the
  exact code sent

The stages are wrapped for that add-in's execution scope, not for Fusion's own script
runner (which expects a `run(context)` entry point). Without the add-in, work from the
F3D or STEP file instead.

`MEASUREMENTS.yaml` is the caliper sheet the parameters came from;
`scripts/sync_params.py` reports which entries are verified. After changing the
design, re-export the meshes into `models/` and regenerate the preview with
`python scripts/render_parts.py`.

---

## Risks

**PLA in a car.** PLA softens around 60 °C, and a closed car in the sun gets well past
that. The arm is the part most likely to droop, since it's cantilevered and always
loaded, and it's also the cheapest to reprint. If it sags after a hot week, reprint
just the arm in PETG; nothing else needs to change.

**Cord reach.** The arm is now 206 mm pivot to pivot. With it vertical and the screen
upright, the power cords leave the case about 202 mm above the console, leaving roughly
103 mm of a 305 mm cord for the run to the socket — tight. Leaning the arm recovers it:
about 122 mm spare at 25° from vertical, 222 mm at 65°. You need two sockets (Pi and LCD).

**Flex buttons in PLA.** The tabs are sized for occasional presses. If one cracks,
reprint the bezel; PETG makes them tougher.

**Touch panel pressure.** If you see phantom touches along the screen edge, the foam is
too thick or too firm; a thinner strip fixes it.

**VHB on textured console plastic** bonds poorly without prep. Clean with isopropyl
alcohol; 3M 4991 is the grade for low-surface-energy plastics.

---

## Files

```
case/
├── README.md                  this guide
├── docs/PRINTING.md           slicer settings, orientations, print order, post-processing
├── MEASUREMENTS.yaml          caliper sheet the parameters were built from
├── images/                    parts preview + reference photos of the Pi/screen stack
├── models/
│   ├── stl/                   one mesh per part (print these)
│   ├── 3mf/                   same parts as 3MF
│   ├── step/                  whole design, neutral CAD
│   └── f3d/                   Fusion 360 archive
└── scripts/
    ├── fusion_build.py        all geometry + parameters (single source of truth)
    ├── push.py                sends stages to a Fusion add-in, logs every push
    ├── sync_params.py         which measurement-sheet values are verified
    ├── fusion_lib.py          shared Fusion API preamble (mm-to-cm helpers)
    └── render_parts.py        regenerates images/parts.png from the STLs
```

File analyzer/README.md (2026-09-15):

# Wardrive Analyzer

The web app for the sessions the Pi uploads to the home server, deployed at
**https://wardrive.russellland.dev** from rustyserver's docker compose stack, behind Keycloak.

- **Map**: every Wi-Fi network and Bluetooth device at the spot its signal peaked, drawn with
  the Pi's colorblind-safe security colors _and_ shapes. Street, dark and satellite basemaps;
  routes from the GPS track; clustering; a density heatmap. Hover for a summary, click for
  details. The map re-frames itself on whatever a search or filter leaves, and the button above
  the zoom controls recenters on everything shown.
- **Filters**: search (text or regex) across SSID, MAC, manufacturer and encryption; security;
  band and channel; minimum signal; sessions and dates; seen in N+ sessions; hidden SSIDs; WPS;
  manufacturer; only what's in view. Filters live in the URL, so any view can be bookmarked.
- **Details**: encryption and login type, WPS device name, band/channel/width, signal range,
  location, every session that saw it, signal over time, where it was heard (on the map), and
  the raw Kismet record.
- **Table**: sortable list of the filtered devices, in sync with the map.
- **Stats**: security mix, manufacturers, devices per session (new vs. seen before), channel
  use, signal distribution, common SSIDs. Click a bar to open those devices on the map.
- **Sessions**: distance, duration and counts per drive; check, fix, and publish to WiGLE.
- **Demo**: the header switch shows the Pi's demo-mode uploads instead. They're kept apart
  from real captures and can never be uploaded.

## How data flows

```
Pi ─► api.russellland.dev /wardrive/upload ─► ../rustyserver/api/data/wardrive/<session>/*.gz
                              │                     (source of truth; mounted read-only here)
                              └─► POST /api/admin/ingest {session, demo}   (X-Admin-Token)
                                        │
                                        ▼
                         Postgres `wardrive` (shared rustyserver-db)
                         sessions · devices · sightings · tracks · reviews · wigle_uploads
                                        │
browser ─► nginx ─► oauth2-proxy (Keycloak) ─► this app ─► /api/devices, /api/tracks, ...
```

- **Ingest** (`src/lib/server/ingest.ts`) unpacks each `.kismet.gz` to `/tmp`, reads it with
  `node:sqlite`, and replaces that session's devices, sightings and tracks in one transaction.
  It runs when the api announces an upload, at startup, every `WARDRIVE_SCAN_MINUTES`, and from
  the rescan buttons. A session is re-read only if its Kismet file changed or `PARSER_VERSION`
  in `kismet.ts` was bumped (bump it whenever what's extracted changes).
- **Reviews** stay in `tools/wardrive_review.py`. The app runs it with `--no-record` and
  `--reviewed-csv <temp file>`: the repaired CSV from **Fix** is stored in `reviews`, loaded back
  for a check or upload, and every WiGLE upload is recorded in `wigle_uploads` along with who
  did it. Nothing is ever written next to the original files.
- **Raw Kismet records** aren't copied into Postgres; they're read from the session file when
  you open one.
- The browser still filters the full device list itself (instant at this size). Past roughly
  50k unique devices that should move into SQL; `src/lib/server/library.ts` is where.

## Publishing to WiGLE

Sessions → **WiGLE…** on a session:

1. A dry run runs the same checks as `wardrive_review.py wigle --dry-run`. If the WiGLE CSV has
   problems (every session from Kismet 2025.09 does: it writes every network as open), the
   dialog offers **Fix and re-check**, which stores a repaired copy in Postgres.
2. It shows exactly what would be sent: rows, size, reviewed or original, and the commercial-use
   (`WIGLE_DONATE`) setting.
3. Nothing is sent until you tick the confirmation and press **Upload to WiGLE**.

A session already in `wigle_uploads` is refused. **Processing status** shows WiGLE's queue for
your account; **Fix all unreviewed** repairs every pending session in one go.

## Deploying

From `../rustyserver`:

```bash
docker compose build wardrive && docker compose up -d wardrive
docker compose logs -f wardrive          # one JSON line per event: ingest, review, admin_ingest
```

The service definitions (`wardrive`, `wardrive-proxy`), the nginx vhost, and the "why" behind
them are documented in rustyserver's `CLAUDE.md` > Wardrive analyzer. The image is built from
this repo's root (`analyzer/Dockerfile`, with `Dockerfile.dockerignore` allowlisting the context).

## Configuration

`../rustyserver/wardrive/wardrive.env` (template: `wardrive.env.example` next to it):

| Variable | Default | |
| --- | --- | --- |
| `POSTGRES_HOST/PORT/DB/USER/PASSWORD` | `postgres`, 5432, `wardrive` ×2 | Role and database from `postgres/entrypoint/50-wardrive.sql` |
| `ADMIN_API_TOKEN` | none | = `WARDRIVE_ADMIN_TOKEN` in `api/api.env`; min 32 chars |
| `WIGLE_API_NAME`, `WIGLE_API_TOKEN`, `WIGLE_DONATE` | none | Passed only to the review tool |
| `ANALYZER_ALLOWED_HOSTS` | none | `wardrive.russellland.dev` |
| `ANALYZER_TRUSTED_PROXY` | none (check off) | `172.20.0.250`, nginx: the only peer the app talks to |
| `WARDRIVE_SCAN_MINUTES` | `15` | Backstop scan interval |
| `WARDRIVE_DATA` | `/data/wardrive` | Set in the image and compose |

## Safety

- Only nginx can reach the UI and API (peer address pinned), and nginx only lets a request
  through after oauth2-proxy confirms a Keycloak session in the `wardrive-users` group.
- Any other `Host` is refused. `/api/admin/*` needs the admin token and is 404 at nginx.
- The data mount and the container filesystem are read-only; the app writes only to `/tmp`
  and its own database.
- Actions are JSON POSTs, which a cross-site form can't send. An upload must name its session
  in the request body, session names must match a session in the database exactly, and demo
  sessions are refused before the tool runs (and again by the tool).

Basemap tiles come from OpenStreetMap (street and dark) and Esri World Imagery (satellite);
each map shows its attribution.

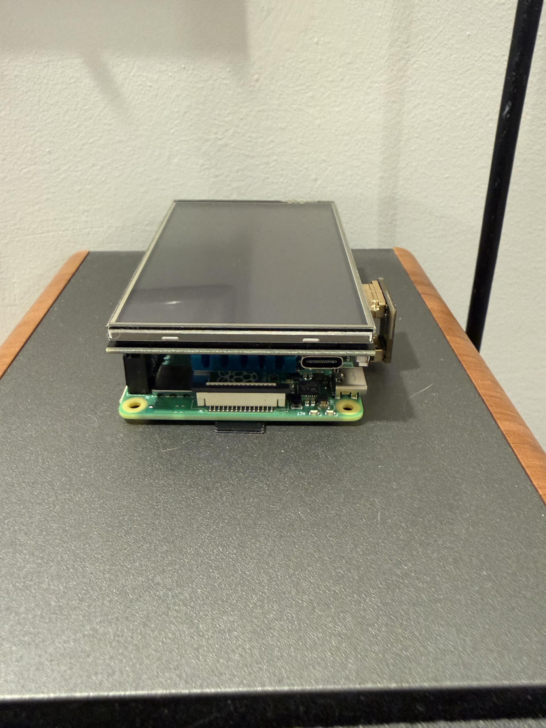
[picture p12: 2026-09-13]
case/images/left.jpeg

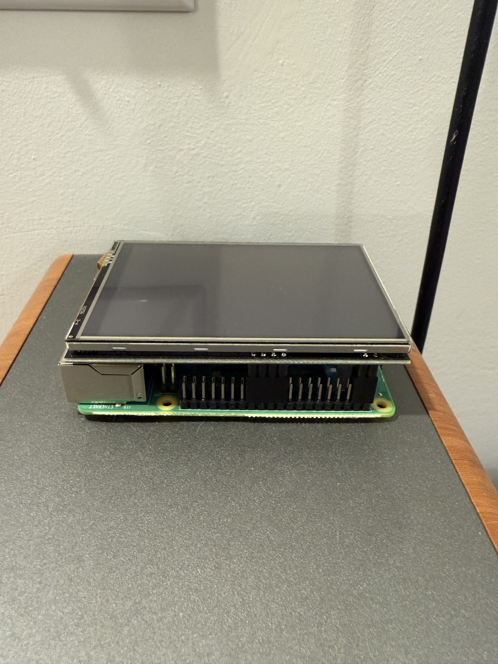
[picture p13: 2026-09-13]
case/images/top.jpeg

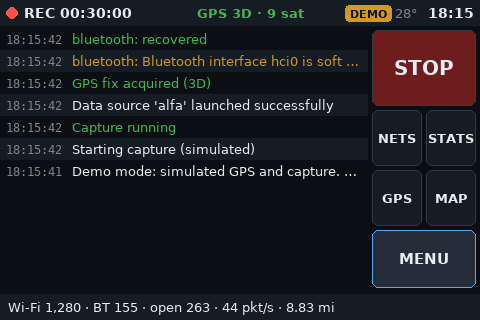
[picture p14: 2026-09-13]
docs/images/log.png

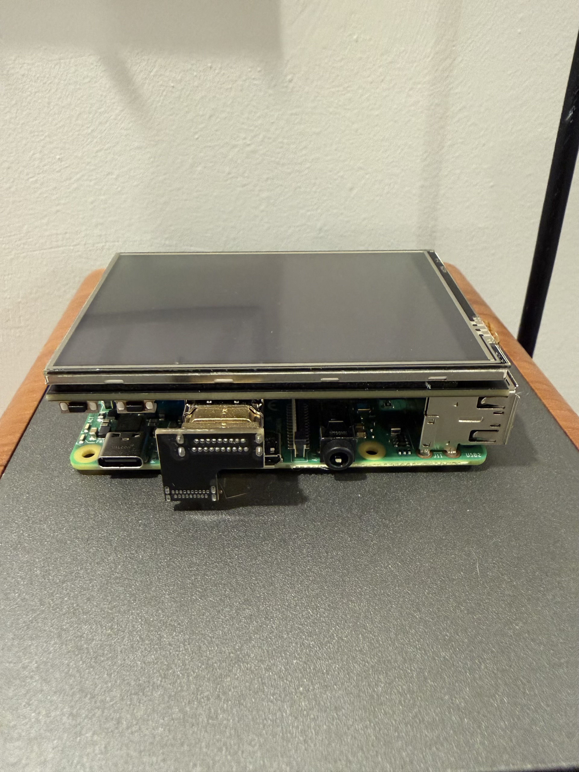
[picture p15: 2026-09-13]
case/images/bottom.jpeg

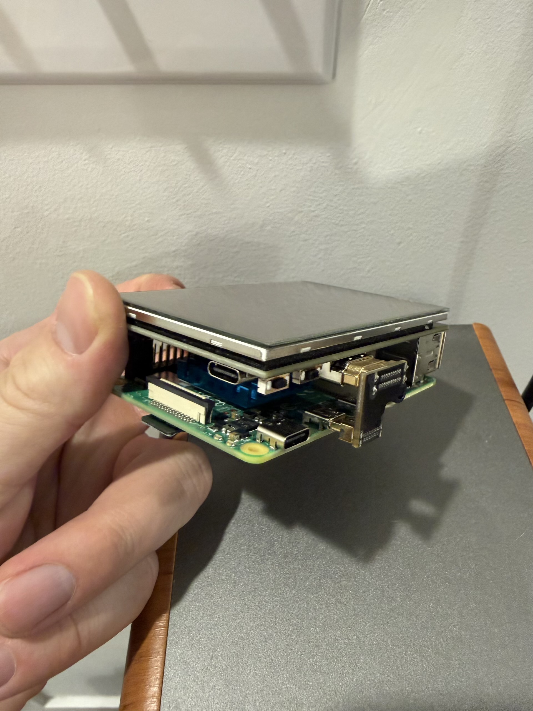
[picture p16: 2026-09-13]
case/images/origin_corner.jpeg

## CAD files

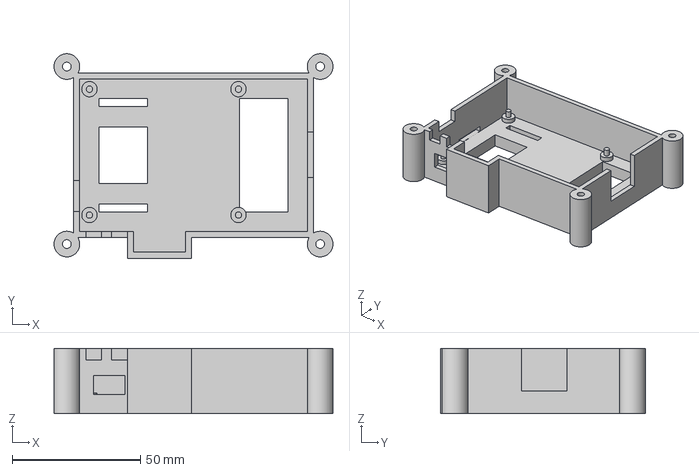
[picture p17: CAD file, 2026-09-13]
case/models/3mf/wardriving-case-back.3mf
108.6 x 79.6 x 25.4 mm

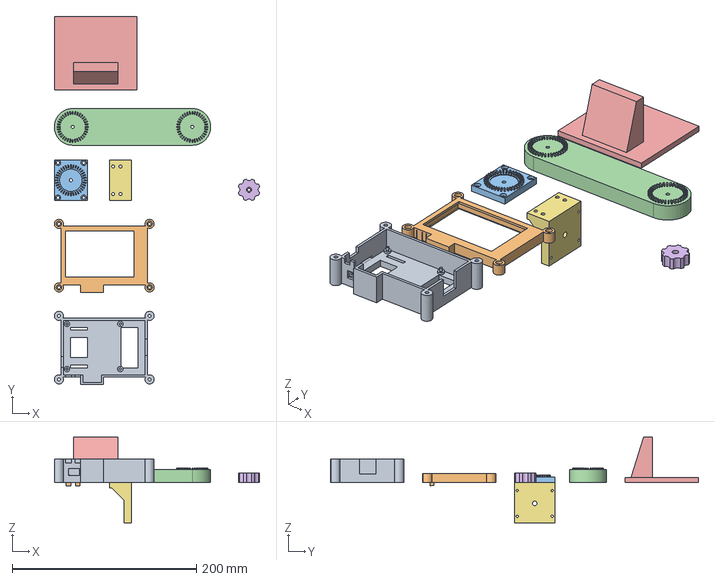
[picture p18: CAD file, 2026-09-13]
case/models/step/wardriving-case.step
223.3 x 400.0 x 93.0 mm

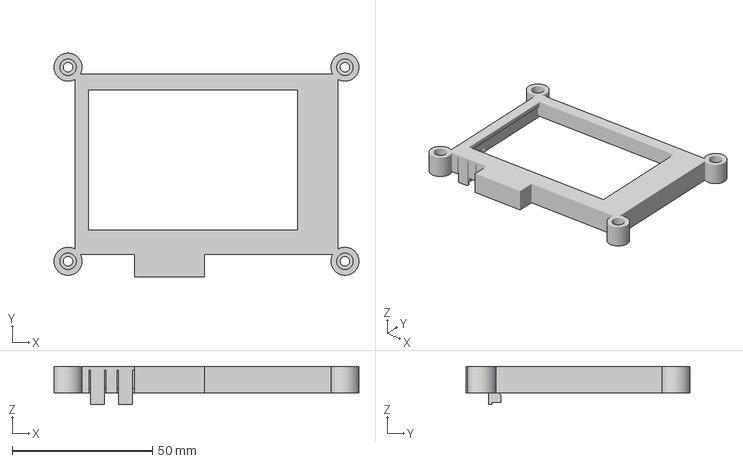
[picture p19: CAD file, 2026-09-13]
case/models/3mf/wardriving-case-bezel.3mf
108.6 x 79.6 x 13.6 mm

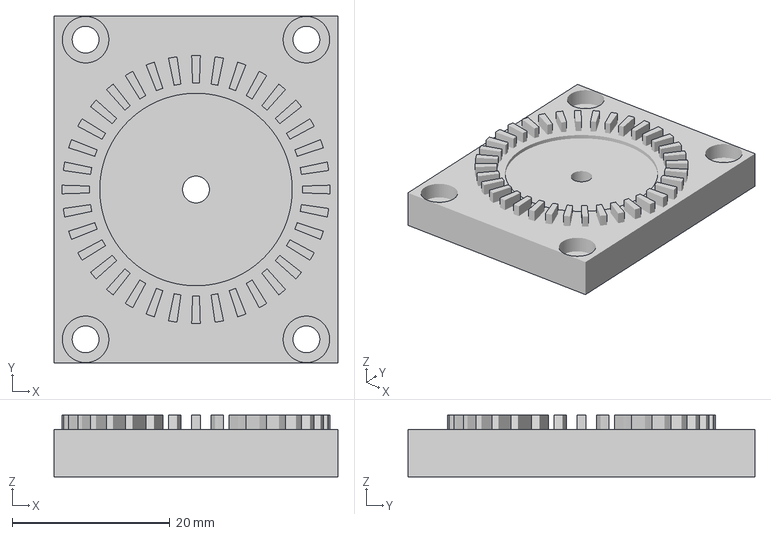
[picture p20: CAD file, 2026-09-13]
case/models/3mf/wardriving-case-tilt_plate.3mf
36.0 x 44.0 x 7.80 mm

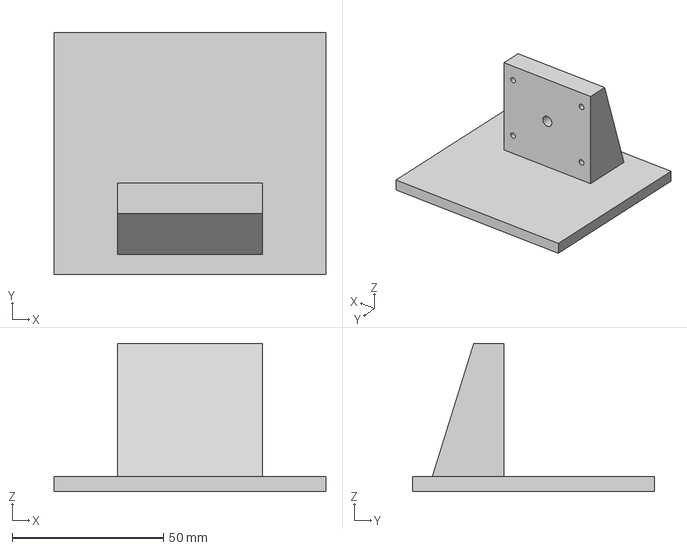
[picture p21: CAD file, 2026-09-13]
case/models/3mf/wardriving-case-base.3mf
90.0 x 80.0 x 49.0 mm

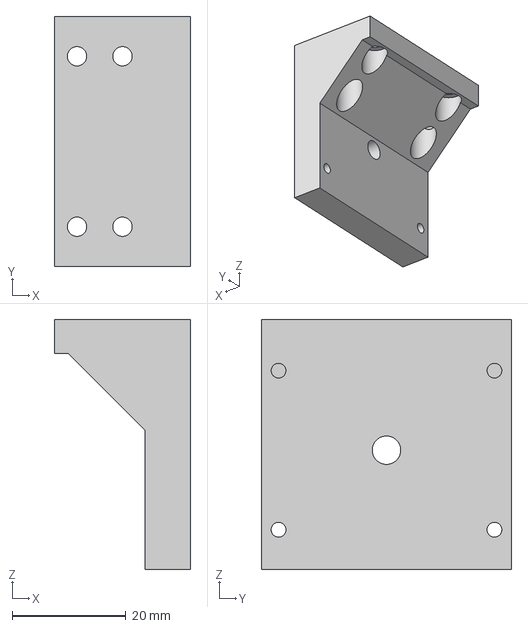
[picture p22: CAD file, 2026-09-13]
case/models/3mf/wardriving-case-knuckle.3mf
24.0 x 44.0 x 44.0 mm

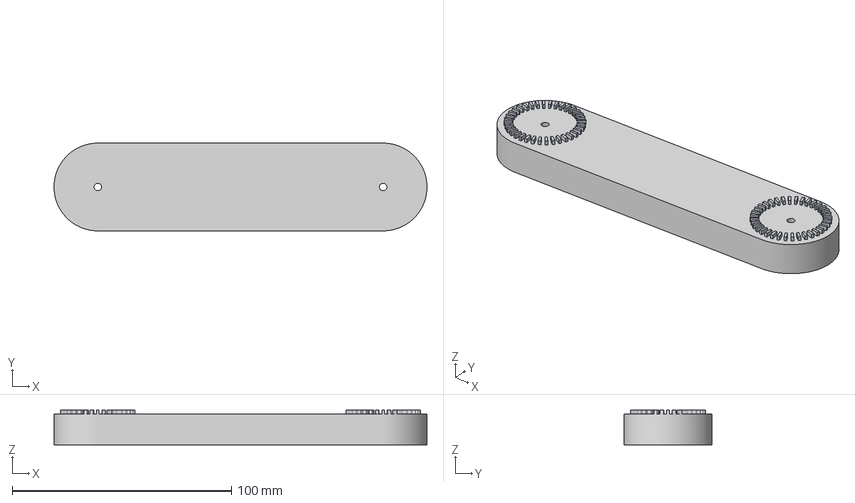
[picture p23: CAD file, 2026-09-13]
case/models/3mf/wardriving-case-arm.3mf
170.0 x 40.0 x 15.8 mm

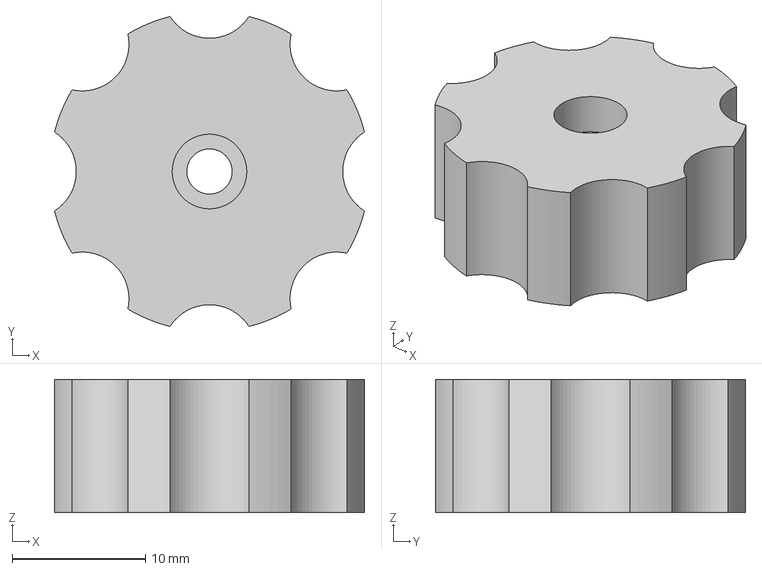
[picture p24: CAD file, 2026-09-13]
case/models/3mf/wardriving-case-knob.3mf
23.3 x 23.3 x 10.0 mm

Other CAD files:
case/models/f3d/wardriving-case.f3d
case/models/stl/wardriving-case-arm.stl
case/models/stl/wardriving-case-back.stl
case/models/stl/wardriving-case-base.stl
case/models/stl/wardriving-case-bezel.stl
case/models/stl/wardriving-case-knob.stl
case/models/stl/wardriving-case-knuckle.stl
case/models/stl/wardriving-case-tilt_plate.stl

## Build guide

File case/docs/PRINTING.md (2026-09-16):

# Printing the case

Tested on an **Elegoo Neptune 3 Pro** (0.4 mm nozzle, PLA) sliced in Cura. The
settings below aren't specific to that printer; start from your own tuned PLA profile
and change what's listed. All parts print **without supports** in the orientations
given.

Back to the [case guide](../README.md).

## Slicer settings

| Setting | Value | Why |
|---|---|---|
| Layer height | 0.2 mm | |
| Line width | 0.42 mm (**0.40 on the bezel**, see below) | |
| Wall line count | **4** | Most of a printed part's strength is in its walls |
| Top / bottom layers | 5 / 5 | |
| Infill | 25 % gyroid (40 % on arm and base, optional) | |
| Supports | **Off** | Every part is modelled to print without them |
| Nozzle / bed temperature | 205 °C / 60 °C | PLA; use what works for your filament |
| Print speed | 50 mm/s, outer walls 30 mm/s | Slower outer walls keep the teeth and holes crisp |
| Retraction | 0.8 mm at 45 mm/s | Direct drive; Bowden printers need more |
| Fan | 100 % from layer 2 | |
| Initial layer horizontal expansion | -0.1 mm | Reduces elephant's foot on bed-facing edges |

## Parts and orientation

| Part (`models/stl/wardriving-case-<part>.stl`) | Qty | Orientation on the bed | Brim | Override | Est. mass |
|---|---|---|---|---|---|
| `back` | 1 | As exported: back face down | optional | — | ~30–35 g |
| `bezel` | 1 | **Flip 180°**: front face down, button tabs and stylus tube pointing up | optional | **Line width 0.40 mm** | ~13–15 g |
| `tilt_plate` | **2** | As exported: teeth up | yes | **Infill 100 %** | ~10 g each |
| `arm` | 1 | Lying flat, teeth up, **rotated 45°** (246 mm won't fit straight) | yes | Infill 40 % (optional) | ~90–100 g |
| `base` | 1 | As exported: plate down, wall up | yes | Infill 40 % (optional) | ~45–55 g |
| `knob` | **2** | As exported: bolt-head pocket up | no | — | ~3 g each |
| `knuckle` | 1 | **Flip 180°**: the flat foot on the bed, upright rising from it | yes | — | ~15–18 g |

Total is roughly 190–220 g. Only two parts need reorienting, and both are a 180° flip:
the bezel and the knuckle.

### Why those orientations

- **The arm lies flat** so its layer lines run along the load path. Printed standing
  up, the layer boundaries at its base would sit in tension, which is where it would
  snap.
- **The bezel prints face-down** so the flex buttons rise as vertical walls and the
  wedge on each tab is a self-supporting 45° slope.
- **The knuckle prints foot-down.** It imports standing on the narrow end of its
  upright, with the foot cantilevered in the air, so flip it 180°. The foot then gives
  a 24 × 44 mm base, and the triangular brace slopes inward going up, so nothing
  overhangs. Its worst-case load is about 0.5 MPa across the layer lines, against
  PLA's roughly 20–40 MPa layer bond.
- **Teeth always point up.** Printed against the bed they'd pick up elephant's foot and
  mesh too tight.

### Per-part overrides

In Cura: right-click a model → Per Model Settings.

- **Bezel: line width 0.40 mm.** The flex buttons are 1.2 mm thick, which is exactly
  three lines at 0.40 but two lines plus gap fill at 0.42. This is the override that
  matters.
- **Tilt plate: infill 100 %.** Tightening the knob bends the middle of the plate
  between the nut and the tooth ring. At 25 % that 5.4 mm centre is two thin skins
  over sparse gyroid. Solid, it's far stiffer, for about 2 g more per plate.
- **Arm and base: infill 40 %.** Optional; they carry the load, but with 4 walls, 25 %
  is already adequate.
- **Brim on the tall and long parts.** The knuckle stands 44 mm tall and the arm is long
  and flat.

**The arm is 246 mm long** and won't lie straight on a 225 mm bed — it needs 253 mm with
a brim. Rotate it 45° in the slicer; diagonally it needs only 212 mm.

**The stylus tube** on the bezel prints as a plain vertical cylinder rising from the bed
alongside the button tabs, so it needs nothing special.

**The case back's 23 vent slots** are vertical, so each one only bridges its 3 mm width.
They need no supports. If a slot top sags slightly, it doesn't matter structurally.

## Suggested order

1. **Both tilt plates first.** They're small, and two of them mesh face to face, so you
   can check that the teeth engage and clamp at 10° steps before committing to big
   prints. **Rotate one half a tooth (5°) to mesh them.** Square-on, the teeth sit
   tip-to-tip and won't seat. That's normal, not a defect.
2. **The bezel.** It has the tightest tolerances in the project. Dry-fit it on the
   screen before printing anything else:
   - the glass should drop into its pocket without forcing
   - the two buttons on the bottom edge should flex and spring back
   - looking through the window, no plastic should cover the lit area
3. **The case back**, then the arm, base, knuckle and knobs in any order.

## After printing

1. **Form the threads.** Run an M3 screw slowly into each tapped hole and back it out:
   four in the case floor, four in the knuckle's upright, four in the base wall. This
   stops a screw from splitting a part during assembly.
2. **Press the nuts in:** four in the case-back ear pockets, and one each in the hex
   pockets on the knuckle's upright and the base wall, where the tilt plates' centres
   land. (The tilt plates have no nut pocket.) They should be snug; use a drop of CA
   glue if one is loose.
3. **Seat a bolt head in each knob.** The head slides 3 mm down a loose lead-in, then
   presses into a tight seat. Pull it home with a nut and washer on the thread, or warm
   the head briefly with a soldering iron and push it in.
4. **Check fit with the real hardware:** the microSD slit and the port openings, before
   final assembly.

Assembly continues in the [case guide](../README.md#assembly).

## Assumptions to check before printing the case back

- **The screen's two buttons are push-type.** If yours slide sideways instead, the flex
  tabs won't work.
- **Both power cords have the same USB-C plug size** (overmold 10.92 × 6.17 mm). A
  chunkier plug may not fit the openings; measure yours with calipers first.

## Exporting meshes (after changing the design)

In Fusion 360, export each body separately: right-click the body → **Save As Mesh** →
**STL (binary)**, units **mm**, refinement **High** (or custom: surface deviation
0.01 mm, normal deviation 5°). The refinement matters: the tilt joints have 36 teeth
about 1.3 mm wide and holes of Ø2.6–3.4 mm, and a coarse mesh turns those circles into
visible polygons so the teeth stop meshing cleanly.

Put the STLs in `models/stl/`, export STEP to `models/step/`, and regenerate the preview
with `python scripts/render_parts.py`. Sliced G-code is git-ignored, since it only works
on the printer and profile it was sliced for.

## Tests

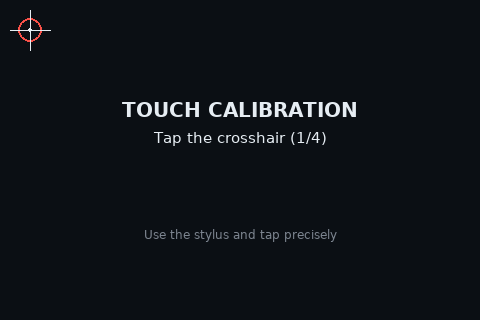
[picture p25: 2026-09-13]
docs/images/calibrate.png

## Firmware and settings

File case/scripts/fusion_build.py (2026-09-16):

#!/usr/bin/env python3
"""Canonical, reproducible source for the wardriving-case Fusion model.

This file is the SINGLE SOURCE OF TRUTH for the geometry. Nothing is typed
ad-hoc into Fusion; every feature comes from here.

Each stage is a block of Fusion 360 API Python. The blocks are executed inside
Fusion by an add-in that accepts scripts over HTTP (not part of this repo;
scripts/push.py sends them). Print a stage's code with:

    python scripts/fusion_build.py params   # print the code for a stage
    python scripts/fusion_build.py 01
    ...

Stages are deliberately small so no single call approaches a 120 s script
timeout.

    python scripts/fusion_build.py --list    # show all stages
    python scripts/fusion_build.py --all     # every stage, in order

Design notes that this script encodes (learned the hard way):
  * every stage is wrapped in `def build():` because the bridge execs in a
    function scope and nested defs cannot see module-level names
  * Join via participantBodies does NOT merge -> always extrude NEW + Combine
  * Combine invalidates body references -> always re-fetch by name
  * a name collision makes Fusion silently rename to "foo (1)", after which
    every by-name lookup targets the WRONG body -> mk() asserts the name it got
  * teeth are patterned, not sketched 36x, or the sketch solver stalls
"""
import sys

GAP = 24.0

# name -> (min-corner x, min-corner y) in mm. Fixed, deterministic, and
# verified non-overlapping by the `verify` stage.
SLOTS = {
    "01_case_back":  (0.0,   0.0),
    "02_case_bezel": (0.0, 100.0),
    "03_tilt_plate": (0.0, 200.0),
    "04_arm":        (0.0, 260.0),
    "05_base":       (0.0, 320.0),
    "06_knob":       (200.0, 200.0),
    "07_knuckle":    (60.0, 200.0),
}

# ---------------------------------------------------------------- parameters
# (name, expression, unit, comment).  Order matters: derived come last.
PARAMS = [
    ("pi_len", "85 mm", "mm", "Pi PCB long edge"),
    ("pi_wid", "56 mm", "mm", "Pi PCB short edge"),
    ("pi_pcb_t", "1.4 mm", "mm", "Pi PCB thickness"),
    ("pi_hole_d", "2.75 mm", "mm", "Pi mount hole dia"),
    ("pi_hole_inset", "3.5 mm", "mm", "hole inset from both edges"),
    ("pi_hole_span_l", "58 mm", "mm", "hole span along length"),
    ("pi_hole_span_w", "49 mm", "mm", "hole span along width"),
    ("pi_top_comp_h", "15.6 mm", "mm", "tallest top component (USB-A stack)"),
    ("pi_under_comp_h", "2 mm", "mm", "solder tails under PCB"),
    ("usbc_ctr", "11.2 mm", "mm", "USB-C centre from origin corner"),
    ("usbc_w", "9.5 mm", "mm", "USB-C opening w"),
    ("usbc_h", "3.6 mm", "mm", "USB-C opening h"),
    ("hdmi0_ctr", "26 mm", "mm", "micro-HDMI0 centre"),
    ("hdmi1_ctr", "39.5 mm", "mm", "micro-HDMI1 centre"),
    ("hdmi_w", "7 mm", "mm", "micro-HDMI opening w"),
    ("hdmi_h", "3.2 mm", "mm", "micro-HDMI opening h"),
    ("av_ctr", "54 mm", "mm", "AV jack centre"),
    ("av_d", "6.6 mm", "mm", "AV jack dia"),
    ("eth_ctr", "45.75 mm", "mm", "ethernet centre - Pi4 puts it at the GPIO end (photos)"),
    ("eth_w", "16 mm", "mm", "ethernet opening w"),
    ("eth_h", "13.5 mm", "mm", "ethernet opening h"),
    ("usb3_ctr", "27 mm", "mm", "USB3 (blue, middle) pair centre"),
    ("usb2_ctr", "9 mm", "mm", "USB2 pair centre - nearest the power edge"),
    ("usb_w", "15 mm", "mm", "USB-A pair opening w"),
    ("usb_h", "16 mm", "mm", "USB-A pair opening h"),
    ("usb_plug_w", "16.5 mm", "mm", "MEASURED plug overmold width"),
    ("usb_plug_h", "9 mm", "mm", "MEASURED plug overmold height"),
    ("usbc_plug_w", "10.92 mm", "mm", "MEASURED Pi power cable overmold width"),
    ("usbc_plug_h", "6.17 mm", "mm", "MEASURED Pi power cable overmold height"),
    ("adp_a", "21.33 mm", "mm", "MEASURED HDMI adapter near side, from origin"),
    ("adp_b", "40.2 mm", "mm", "MEASURED HDMI adapter far side, from origin"),
    ("adp_out", "10.34 mm", "mm", "MEASURED adapter reach past Pi pcb edge"),
    ("adp_below", "0 mm", "mm", "measured body_h puts the adapter's low point ~9.25, above the floor"),
    ("adp_hood", "1", "", "1 = enclose the HDMI adapter in a local hood, 0 = open notch"),
    ("adp_clr", "0.6 mm", "mm", "clearance around the HDMI adapter (was 1.0 at the sides)"),
    ("lcd_usbc_ctr", "10.97 mm", "mm", "MEASURED LCD USB-C centre, left edge, from origin"),
    ("lcd_usbc_plug_w", "10.92 mm", "mm", "ASSUMED same cord as the Pi power cable"),
    ("lcd_usbc_plug_h", "6.17 mm", "mm", "ASSUMED same cord as the Pi power cable"),
    ("lcd_usbc_below", "1.8 mm", "mm", "LCD USB-C centre below LCD pcb (open_h 3.43 / 2)"),
    ("fpc_relief", "1.5 mm", "mm", "touch-panel flex wraps the right edge of the glass"),
    ("edge_clear_b", "2.5 mm", "mm", "extra room on power edge: USB-C/AV protrude past pcb"),
    ("edge_clear_r", "3 mm", "mm", "extra room on USB edge: USB-A/ethernet protrude"),
    ("usb3_open", "0", "", "1 = open the blue USB3 stack (merged into one notch if USB2 is open too)"),
    ("usb2_open", "1", "", "1 = open the black USB2 stack - where the GPS and Wi-Fi adapter live"),
    ("btn_pwr_a", "3.78 mm", "mm", "MEASURED PWR button near side, bottom edge, from origin"),
    ("btn_pwr_b", "6.59 mm", "mm", "MEASURED PWR button far side"),
    ("btn_bkl_a", "14 mm", "mm", "MEASURED BKL button near side"),
    ("btn_bkl_b", "17.94 mm", "mm", "MEASURED BKL button far side"),
    ("btn_pwr_ctr", "(btn_pwr_a + btn_pwr_b) / 2", "mm", "PWR button centre"),
    ("btn_bkl_ctr", "(btn_bkl_a + btn_bkl_b) / 2", "mm", "BKL button centre"),
    ("sw_below", "2 mm", "mm", "MEASURED button centre below the LCD pcb back face"),
    ("sw_out", "0.63 mm", "mm", "MEASURED button tip past the LCD pcb edge"),
    ("tab_w", "5 mm", "mm", "flex button tab width"),
    ("tab_t", "1.2 mm", "mm", "flex button tab thickness (flush with the case outside)"),
    ("tab_slit", "0.6 mm", "mm", "slit either side of a flex tab"),
    ("tab_cav", "2.4 mm", "mm", "clearance cavity behind a flex tab"),
    ("tab_root_skin", "1.2 mm", "mm", "bezel face left above the tab hinge"),
    ("nub_h", "2.5 mm", "mm", "nub height at the button"),
    ("nub_gap", "0.3 mm", "mm", "nub to button at rest"),
    ("tab_press", "0.8 mm", "mm", "design deflection at the nub when pressed"),
    ("gasket", "0.5 mm", "mm", "compressed foam between bezel lip and glass border"),
    ("sd_ctr", "28 mm", "mm", "microSD centre on short edge"),
    ("sd_w", "14 mm", "mm", "microSD slot width"),
    ("sd_below", "1.6 mm", "mm", "SD slot drop below PCB"),
    ("lcd_len", "85 mm", "mm", "LCD pcb length"),
    ("lcd_wid", "56 mm", "mm", "LCD pcb width"),
    ("lcd_pcb_t", "1.6 mm", "mm", "LCD pcb thickness"),
    ("lcd_active_w", "73.44 mm", "mm", "active area w"),
    ("lcd_active_h", "48.96 mm", "mm", "active area h"),
    ("lcd_active_off_x", "2.52 mm", "mm", "MEASURED lit-area offset x"),
    ("lcd_active_off_y", "3.78 mm", "mm", "MEASURED lit-area offset y"),
    ("lcd_panel_h", "5.4 mm", "mm", "DERIVED: total 24.4 - pi 1.4 - gap 16 - lcd 1.6"),
    ("glass_w", "84.13 mm", "mm", "MEASURED glass slab width (covers ~whole LCD board)"),
    ("glass_h", "54.82 mm", "mm", "MEASURED glass slab height"),
    ("glass_off_x", "0 mm", "mm", "MEASURED glass offset x"),
    ("glass_off_y", "0 mm", "mm", "MEASURED glass offset y"),
    ("stack_gap", "16 mm", "mm", "MEASURED Pi pcb top to LCD pcb bottom"),
    ("fit_port", "0.6 mm", "mm", "clearance around port openings"),
    ("fit_board", "0.4 mm", "mm", "clearance around PCB edges"),
    ("wall", "2.4 mm", "mm", "wall thickness"),
    ("floor_t", "6 mm", "mm", "floor thickness (NB: 'floor' is reserved)"),
    ("hole_comp", "0.2 mm", "mm", "hole diameter compensation"),
    ("bezel_grip", "2 mm", "mm", "bezel lip overlap onto LCD pcb"),
    ("bezel_face_t", "2 mm", "mm", "bezel front face thickness"),
    ("m3_clear", "3.4 mm", "mm", "M3 clearance hole"),
    ("m3_tap", "2.6 mm", "mm", "M3 self-tap into PLA"),
    ("m3_head_d", "5.5 mm", "mm", "M3 head diameter"),
    ("m3_nut_af", "5.5 mm", "mm", "M3 nut across flats"),
    ("m3_nut_t", "2.4 mm", "mm", "M3 nut thickness"),
    ("m3_head_h", "3 mm", "mm", "M3 socket head height"),
    ("bezel_screw_l", "30 mm", "mm", "M3 screw length the ear nut pockets are sized for"),
    ("kn_case_screw_l", "8 mm", "mm", "M3 screws, knuckle foot to case back"),
    ("kn_plate_screw_l", "8 mm", "mm", "M3 screws, tilt plate to knuckle upright"),
    ("base_plate_screw_l", "12 mm", "mm", "M3 screws, base tilt plate to base wall"),
    ("tilt_bolt_l", "30 mm", "mm", "M3 socket-head tilt bolts (longest on hand)"),
    ("tilt_washer_t", "0.6 mm", "mm", "flat washer between each knob and the arm"),
    ("case_tap_d", "5 mm", "mm", "tapped depth in the case floor (floor is floor_t)"),
    ("base_tap_d", "10 mm", "mm", "tapped depth in the base wall (was 8; deepened for M3 x 12)"),
    ("peg_d", "2.5 mm", "mm", "Pi locating peg dia"),
    ("peg_h", "3 mm", "mm", "Pi locating peg height"),
    ("standoff_d", "6 mm", "mm", "Pi standoff boss dia"),
    ("ear_d", "10 mm", "mm", "corner ear boss dia"),
    ("spine_w", "36 mm", "mm", "solid back spine width"),
    ("frame_w", "10 mm", "mm", "back perimeter frame width"),
    ("tilt_teeth", "36", "", "tooth count = 10deg steps"),
    ("tooth_half", "2.0 deg", "deg", "half angular width of an ARM tooth (was 2.2)"),
    ("plate_tooth_half", "1.85 deg", "deg", "half width of a PLATE tooth - narrower so new plates mesh with an already-printed arm too"),
    ("tooth_relief_r", "12.2 mm", "mm", "plate centre relief radius: clears a printed arm's fused inner ring"),
    ("tooth_relief_d", "0.6 mm", "mm", "plate centre relief depth"),
    ("tilt_hub_d", "34 mm", "mm", "toothed hub diameter"),
    ("tilt_tooth_h", "1.8 mm", "mm", "tooth depth"),
    ("tilt_r_in", "13.5 mm", "mm", "tooth ring inner radius (was 7: unprintable; 13.5 keeps plate teeth >= 2 extrusions)"),
    ("tilt_plate_t", "6 mm", "mm", "tilt plate base thickness"),
    ("tp_bolt_dx", "14 mm", "mm", "tilt plate bolt spacing x/2"),
    ("tp_bolt_dy", "19 mm", "mm", "tilt plate bolt spacing y/2"),
    ("pad_w", "36 mm", "mm", "tilt plate pad width"),
    ("pad_l", "44 mm", "mm", "tilt plate pad length"),
    ("arm_h", "206.2 mm", "mm", "pivot to pivot (was 130; +3 in per user 2026-09-13)"),
    ("arm_w", "40 mm", "mm", "arm width"),
    ("arm_t", "14 mm", "mm", "arm thickness"),
    ("base_l", "90 mm", "mm", "base footprint length"),
    ("base_w", "80 mm", "mm", "base footprint width"),
    ("base_t", "5 mm", "mm", "base plate thickness"),
    ("base_pivot_z", "arm_w / 2 + 3 mm", "mm", "base pivot above plate top: arm end radius + 3mm (was 20 = touching)"),
    ("wall_x", "48 mm", "mm", "base wall width, fore-aft"),
    ("wall_t_top", "10 mm", "mm", "base wall thickness at top"),
    ("wall_t_bot", "24 mm", "mm", "base wall thickness at bottom"),
    ("wall_h", "44 mm", "mm", "base wall height above plate top"),
    ("knob_d", "24 mm", "mm", "tilt knob diameter"),
    ("knob_t", "10 mm", "mm", "tilt knob thickness"),
    ("knob_floor_t", "3.9 mm", "mm", "knob under the bolt head (was 6.9: head sunk 3mm so an M3 x 30 reaches the nut behind the plate)"),
    ("tilt_tip_relief_d", "6 mm", "mm", "bolt-tip hole depth in the base wall behind the nut pocket (the knuckle's goes through)"),
    ("kn_fb_t", "8 mm", "mm", "knuckle upright thickness"),
    ("kn_fa_l", "16 mm", "mm", "knuckle foot length behind the upright"),
    ("kn_fa_t", "6 mm", "mm", "knuckle foot thickness"),
    ("kn_w", "44 mm", "mm", "knuckle width (tilt plate long side)"),
    ("kn_h", "arm_w / 2 + 3 mm", "mm", "top joint axis behind the case back: arm end radius + 3mm"),
    ("kn_sx1", "4 mm", "mm", "foot screw row 1, from the upright's back face"),
    ("kn_sx2", "12 mm", "mm", "foot screw row 2"),
    ("kn_sy", "15 mm", "mm", "foot screws half-spacing along the case height"),
    ("kn_gusset_ang", "30 deg", "deg", "gusset slope off the foot (was 45: row-1 screws sat 9mm down their tunnels)"),
    # derived
    ("case_in_l", "pi_len + 2 * fit_board + edge_clear_r", "mm", "inner pocket length"),
    ("case_in_w", "pi_wid + 2 * fit_board + edge_clear_b", "mm", "inner pocket width"),
    ("case_out_l", "case_in_l + 2 * wall", "mm", "outer shell length"),
    ("case_out_w", "case_in_w + 2 * wall", "mm", "outer shell width"),
    ("stack_total", "pi_pcb_t + stack_gap + lcd_pcb_t + lcd_panel_h", "mm", "sandwich"),
    ("pcb_top_z", "floor_t + pi_under_comp_h + pi_pcb_t", "mm", "Pi PCB top from shell back"),
    ("rim_h", "floor_t + pi_under_comp_h + pi_pcb_t + stack_gap", "mm", "back shell rim height"),
    ("bezel_h", "lcd_pcb_t + lcd_panel_h + gasket + bezel_face_t", "mm", "bezel total height"),
    ("tilt_r_out", "tilt_hub_d / 2", "mm", "tooth ring outer radius"),
    ("tilt_step", "360 deg / tilt_teeth", "deg", "angle per tooth"),
    ("yoke_off", "tilt_plate_t + tilt_tooth_h + arm_t / 2", "mm", "face to arm centreline"),
    ("tilt_nut_pocket_d", "m3_nut_t + 0.3 mm", "mm", "tilt nut pocket depth, in the knuckle upright and base wall behind each plate"),
    ("ear_nut_d", "rim_h + bezel_h - 3.2 mm - (bezel_screw_l - 1 mm) + m3_nut_t", "mm",
     "ear nut pocket depth: an M3 x bezel_screw_l ends 1mm past the nut"),
    ("stylus_d", "4.88 mm", "mm", "MEASURED stylus barrel diameter (2026-09-13; was 5.0)"),
    ("stylus_len", "110 mm", "mm", "ASSUMED stylus length (unmeasured, conservative) - clearance checks only"),
    ("stylus_bore", "5.2 mm", "mm", "tube bore: prints ~5.0, snug slip fit on the 4.88 barrel (was 5.4: loose)"),
    ("stylus_wall", "2 mm", "mm", "tube wall"),
    ("stylus_tube_l", "22 mm", "mm", "tube length back from the bezel front face"),
    ("stylus_x", "-(stylus_bore / 2 + stylus_wall + 0.8 mm)", "mm", "tube centre, case x: just outside the left wall, 0.8mm clear"),
    ("stylus_y", "case_out_w - 10 mm", "mm", "tube centre, case y: top-left, below the corner ear"),
    ("vent_w", "3 mm", "mm", "vent slot width (vertical slots: bridges only this when printing)"),
    ("vent_rib", "3 mm", "mm", "minimum solid rib between slots and around any existing opening"),
    ("vent_band", "2 mm", "mm", "solid band kept above the floor and below the rim"),
    ("vent_corner", "8 mm", "mm", "solid wall kept at each corner (ears carry the bezel screws)"),
]

HELPERS = r'''
import adsk.core, adsk.fusion, math, traceback
app = adsk.core.Application.get()
des = adsk.fusion.Design.cast(app.activeProduct)
root = des.rootComponent
UP = des.userParameters
FO = adsk.fusion.FeatureOperations
NEW, CUT = FO.NewBodyFeatureOperation, FO.CutFeatureOperation

def P(n):
    p = UP.itemByName(n)
    if p is None: raise RuntimeError('missing parameter: ' + n)
    return p.value * 10.0

def PD(n): return math.degrees(UP.itemByName(n).value)
def c(m): return m / 10.0
def vr(m): return adsk.core.ValueInput.createByReal(c(m))
def pt(x, y, z=0): return adsk.core.Point3D.create(c(x), c(y), c(z))

def bod(nm):
    b = root.bRepBodies.itemByName(nm)
    if b is None: raise RuntimeError('no body named ' + nm)
    return b

def newsk(): return root.sketches.add(root.xYConstructionPlane)
def newxz(): return root.sketches.add(root.xZConstructionPlane)
def newyz(): return root.sketches.add(root.yZConstructionPlane)
def rect(sk,x0,y0,x1,y1): sk.sketchCurves.sketchLines.addTwoPointRectangle(pt(x0,y0),pt(x1,y1))
def circ(sk,cx,cy,d): sk.sketchCurves.sketchCircles.addByCenterRadius(pt(cx,cy),c(d/2.0))

def hexa(sk,cx,cy,af,a0=30.0):
    """Hexagon across flats af; a0 = angle of the first vertex (30 puts one on sketch v, 0 on u)."""
    r = af / math.sqrt(3.0); L = sk.sketchCurves.sketchLines
    ps=[pt(cx+r*math.cos(math.radians(60*i+a0)), cy+r*math.sin(math.radians(60*i+a0))) for i in range(6)]
    for i in range(6): L.addByTwoPoints(ps[i], ps[(i+1)%6])

def profs(sk):
    oc = adsk.core.ObjectCollection.create()
    for p in sk.profiles: oc.add(p)
    if oc.count == 0: raise RuntimeError('sketch produced no profiles')
    return oc

def _ext(sk, z0, h, op, target=None):
    f = root.features.extrudeFeatures
    inp = f.createInput(profs(sk), op)
    if abs(z0) > 1e-9:
        inp.startExtent = adsk.fusion.OffsetStartDefinition.create(vr(z0))
    inp.setDistanceExtent(False, vr(h))
    if target is not None: inp.participantBodies = [target]
    return f.add(inp)

def mk(sk, z0, h, name):
    """New body, asserting Fusion did not silently rename it on collision."""
    if root.bRepBodies.itemByName(name) is not None:
        raise RuntimeError('body already exists, refusing to shadow: ' + name)
    r = _ext(sk, z0, h, NEW)
    b = r.bodies.item(0); b.name = name
    if b.name != name:
        raise RuntimeError('rename collision: asked %s got %s' % (name, b.name))
    return b

def cut(nm, sk, z0, h): _ext(sk, z0, h, CUT, bod(nm))

def _merge(nm, newbodies, op=None):
    tools = adsk.core.ObjectCollection.create()
    for b in newbodies: tools.add(b)
    ci = root.features.combineFeatures.createInput(bod(nm), tools)
    ci.operation = FO.JoinFeatureOperation if op is None else op
    ci.isKeepToolBodies = False
    root.features.combineFeatures.add(ci)

def addto(nm, sk, z0, h): _merge(nm, list(_ext(sk, z0, h, NEW).bodies))

def addtosym(nm, sk, dist):
    f = root.features.extrudeFeatures
    inp = f.createInput(profs(sk), NEW)
    inp.setSymmetricExtent(vr(dist), True)
    _merge(nm, list(f.add(inp).bodies))

def teeth(nm, cx, cy, z0, h, half=None):
    """One tooth at the origin, circular-patterned about the built-in Z axis,
    then moved to (cx, cy). Parametric designs refuse free construction axes
    ('Environment is not supported'), and 36 sketched sectors stall the solver."""
    n = int(round(UP.itemByName('tilt_teeth').value))
    if half is None: half = PD('tooth_half')
    ri = P('tilt_r_in'); ro = P('tilt_r_out')
    step = 360.0/n
    tw = math.radians(2*half)*ri; gw = math.radians(step-2*half)*ri
    if tw < 0.84 or gw < 0.84:
        raise RuntimeError('teeth unprintable at r_in=%.1f: tooth %.2fmm, gap %.2fmm '
                           '(need >= 0.84mm = two 0.42 extrusions)' % (ri, tw, gw))
    before = set(b.name for b in root.bRepBodies)
    a0 = math.radians(-half); a1 = math.radians(half)
    sk = newsk(); L = sk.sketchCurves.sketchLines; A = sk.sketchCurves.sketchArcs
    p1 = pt(ri*math.cos(a0), ri*math.sin(a0)); p2 = pt(ro*math.cos(a0), ro*math.sin(a0))
    p3 = pt(ro*math.cos(a1), ro*math.sin(a1)); p4 = pt(ri*math.cos(a1), ri*math.sin(a1))
    L.addByTwoPoints(p1, p2); A.addByThreePoints(p2, pt(ro, 0), p3)
    L.addByTwoPoints(p3, p4); A.addByThreePoints(p4, pt(ri, 0), p1)
    tooth = _ext(sk, z0, h, NEW).bodies.item(0)
    oc = adsk.core.ObjectCollection.create(); oc.add(tooth)
    ci = root.features.circularPatternFeatures.createInput(oc, root.zConstructionAxis)
    ci.quantity = adsk.core.ValueInput.createByReal(n)
    ci.totalAngle = adsk.core.ValueInput.createByString('360 deg')
    ci.isSymmetric = False
    root.features.circularPatternFeatures.add(ci)
    fresh = [b for b in root.bRepBodies if b.name not in before]
    if len(fresh) != n:
        raise RuntimeError('expected %d teeth, got %d' % (n, len(fresh)))
    if abs(cx) > 1e-9 or abs(cy) > 1e-9:
        oc = adsk.core.ObjectCollection.create()
        for b in fresh: oc.add(b)
        mf = root.features.moveFeatures; mi = mf.createInput2(oc)
        m = adsk.core.Matrix3D.create()
        m.translation = adsk.core.Vector3D.create(c(cx), c(cy), 0)
        mi.defineAsFreeMove(m); mf.add(mi)
        fresh = [b for b in root.bRepBodies if b.name not in before]   # refs stale after move
    _merge(nm, fresh)
    return n

def place(nm, sx, sy):
    """Move body so its bbox min corner lands exactly on (sx, sy). Deterministic."""
    b = bod(nm); bb = b.boundingBox
    dx = sx - bb.minPoint.x * 10.0
    dy = sy - bb.minPoint.y * 10.0
    oc = adsk.core.ObjectCollection.create(); oc.add(b)
    mf = root.features.moveFeatures; inp = mf.createInput2(oc)
    m = adsk.core.Matrix3D.create()
    m.translation = adsk.core.Vector3D.create(c(dx), c(dy), 0)
    inp.defineAsFreeMove(m); mf.add(inp)

def report(nm):
    b = bod(nm); bb = b.boundingBox
    return {'name': nm, 'vol_cm3': round(b.volume, 2), 'valid': b.isValid,
            'bbox': [round((bb.maxPoint.x-bb.minPoint.x)*10,1),
                     round((bb.maxPoint.y-bb.minPoint.y)*10,1),
                     round((bb.maxPoint.z-bb.minPoint.z)*10,1)],
            'min': [round(bb.minPoint.x*10,1), round(bb.minPoint.y*10,1)],
            'bodies_total': root.bRepBodies.count}

def probe(pl, u, v):
    s = root.sketches.add(pl); circ(s, u, v, 4)
    f = root.features.extrudeFeatures; i = f.createInput(profs(s), NEW)
    i.setSymmetricExtent(vr(4), True); b = f.add(i).bodies.item(0); bb = b.boundingBox
    r = [(bb.minPoint.x+bb.maxPoint.x)/2*10, (bb.minPoint.y+bb.maxPoint.y)/2*10,
         (bb.minPoint.z+bb.maxPoint.z)/2*10]
    b.deleteMe(); return r

def planemap(pl):
    """Which model axis each sketch axis lands on, with sign. On the YZ plane
    Fusion swaps them (sketch u -> model -z, v -> +y); assuming no swap once
    laid the base wall down flat."""
    cen = probe(pl, 10, 20)
    iu = min(range(3), key=lambda k: abs(abs(cen[k])-10))
    iv = min(range(3), key=lambda k: abs(abs(cen[k])-20))
    if iu == iv: raise RuntimeError('ambiguous plane probe %s' % cen)
    return (iu, 1.0 if cen[iu] > 0 else -1.0, iv, 1.0 if cen[iv] > 0 else -1.0)

def skp(mp, x, y, z):
    m = (x, y, z); iu, su, iv, sv = mp
    return m[iu]*su, m[iv]*sv
'''
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

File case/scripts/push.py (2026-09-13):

#!/usr/bin/env python3
"""Push fusion_build.py stages straight to the Fusion add-in. No hand-pasting.

    python scripts/push.py status                 # add-in health check
    python scripts/push.py info                   # active doc, body count
    python scripts/push.py newdoc params 01 02    # run stages in order
    python scripts/push.py --all                  # params + 01..06 + verify
    python scripts/push.py cmd save_as '{"name": "wardriving-case-clean"}'

Stops at the first stage that errors. Every push is appended to
logs/build_log.jsonl with a timestamp and the sha256 of the exact code sent,
so any model state can be traced back to the script revision that made it.
"""
import hashlib, json, os, pathlib, sys, time, urllib.error, urllib.request

HERE = pathlib.Path(__file__).resolve().parent
sys.path.insert(0, str(HERE))
import fusion_build as fb  # noqa: E402

URL = os.environ.get("FUSION_BRIDGE_URL", "http://127.0.0.1:7432/")
LOG = HERE.parent / "logs" / "build_log.jsonl"


def post(payload, timeout=300):
    req = urllib.request.Request(URL, data=json.dumps(payload).encode(),
                                 headers={"Content-Type": "application/json"})
    t0 = time.time()
    try:
        with urllib.request.urlopen(req, timeout=timeout) as r:
            raw = r.read().decode()
    except urllib.error.URLError as e:
        return {"error": "unreachable: %s" % e}, time.time() - t0
    try:
        return json.loads(raw), time.time() - t0
    except ValueError:
        return {"error": "non-JSON reply", "raw": raw[:500]}, time.time() - t0


def log(entry):
    LOG.parent.mkdir(exist_ok=True)
    with LOG.open("a") as f:
        f.write(json.dumps(entry) + "\n")


def failed(resp):
    if "error" in resp:
        return True
    out = resp.get("output")
    return isinstance(out, dict) and "ERROR" in out


def run_stage(stage):
    code = fb.build_code(stage)
    sha = hashlib.sha256(code.encode()).hexdigest()[:12]
    resp, dt = post({"command": "execute_script", "params": {"code": code}})
    log({"t": time.strftime("%Y-%m-%dT%H:%M:%S"), "stage": stage, "sha": sha,
         "secs": round(dt, 1), "ok": not failed(resp), "resp": resp})
    print("[%s] sha=%s %.1fs -> %s" % (stage, sha, dt, json.dumps(resp.get("output", resp))))
    return not failed(resp)


def main(argv):
    if not argv or argv[0] in ("-h", "--help"):
        print(__doc__); return 0
    if argv[0] == "status":
        resp, dt = post({"command": "fusion_status"}, timeout=40)
        print("%.1fs %s" % (dt, json.dumps(resp))); return 0 if "error" not in resp else 1
    if argv[0] == "cmd":
        params = json.loads(argv[2]) if len(argv) > 2 else None
        resp, dt = post({"command": argv[1], "params": params})
        log({"t": time.strftime("%Y-%m-%dT%H:%M:%S"), "cmd": argv[1], "params": params,
             "secs": round(dt, 1), "resp": resp})
        print("%.1fs %s" % (dt, json.dumps(resp))); return 0 if "error" not in resp else 1
    stages = ["params"] + fb.ORDER if argv[0] == "--all" else argv
    for s in stages:
        if not run_stage(s):
            print("STOPPED at stage %s" % s); return 1
    return 0


if __name__ == "__main__":
    sys.exit(main(sys.argv[1:]))

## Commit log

2026-09-13 migrate case builds to this repo, add map feature, session browse feature and extensive logs
    [wardriving-case-arm.3mf, wardriving-case-arm.stl, wardriving-case-back.3mf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]
2026-09-13 add venelation to case and make colors more colorblind-friendly
2026-09-16 move USB to black ports, fix tilt plate failures
    [fusion_build.py]
